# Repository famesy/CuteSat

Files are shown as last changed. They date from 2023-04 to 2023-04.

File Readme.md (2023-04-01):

# CubeSat PCB Design for Reliable Space Missions

CubeSat is an affordable and popular educational platform for deploying payloads into orbit. However, many university-level missions fail at a rate of around 50%. The primary reason for this is the difficulty of adapting an existing design, which results in poorly designed hardware for the harsh environment of space and a lack of failure handling software.

To address this problem, we have developed an expandable, low-cost printed circuit board (PCB) that can be stacked and includes the following components:

- Power supply unit
- Microcontroller
- Several sensors
- Watchdog
- Communication bus isolation
- External memory

We have used a component selection methodology that is based on existing research and adapted it to our design. We have also implemented a software Hamming error-correction code to protect the data.

Since our PCBs are modular, readers can design their own system using our design as a starting point. We offer failure handler software and hardware that can be easily integrated into their design. Our ultimate goal is to make space studies more accessible to everyone, increase the success rate, and allow people to focus on their missions rather than the hectic development.

Lastly, we intend to make our project open source so that it can continue to grow and improve over time. We hope that this project will develop into a community where people can discuss their designs and share their changes and knowledge for various missions.

Thank you for considering our CubeSat PCB design for your space mission needs.

## Project Components
This project includes two distinct folders: hardware and software.

### Hardware
The hardware folder contains four PCB designs that were used in our mission:

#### MCU (base PCB)

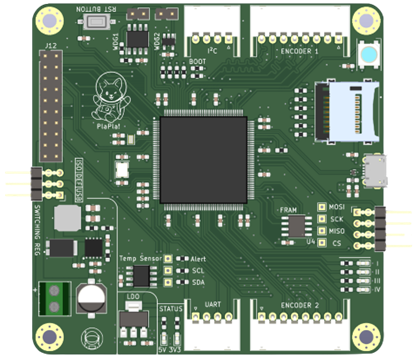
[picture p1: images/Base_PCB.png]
Base PCB


#### Motor driver (payload PCB)

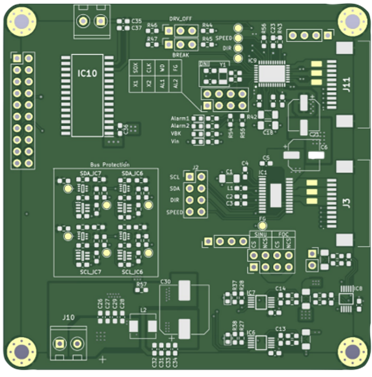
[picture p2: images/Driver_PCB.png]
Driver PCB


#### Encoder (payload PCB)

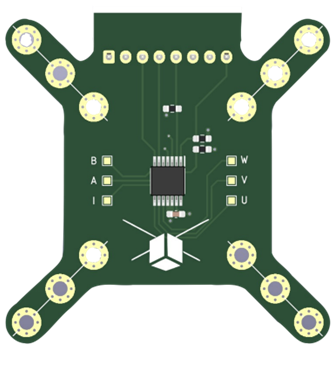
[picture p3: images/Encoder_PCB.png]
Encoder PCB


#### ST-Link adapter

### Software
The software folder contains STM32 projects that include libraries for interfacing with the sensors and implementing error detection and correction algorithms.

### How its look when assemble

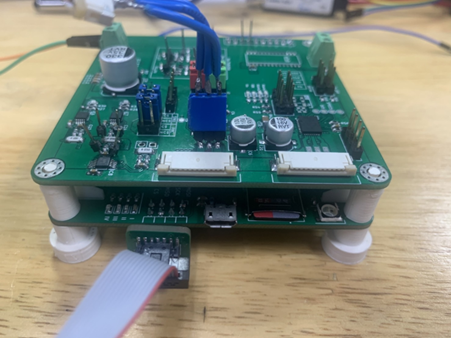
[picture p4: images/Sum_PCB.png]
SUM PCB


####Thank you for your interest in our project!

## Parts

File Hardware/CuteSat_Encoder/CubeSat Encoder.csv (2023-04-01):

Source: | C:\Users\fame\Documents\KiCad Projects\CubeSat Encoder\CubeSat Encoder.kicad_sch
Date: | 19/01/2022 13:51:59
Tool: | Eeschema (6.0.0)
Generator: | C:\Program Files\KiCad\6.0\bin\scripting\plugins/bom_csv_grouped_by_value.py
Component Count: | 16
Individual Components:
Item | Qty | Reference(s) | Value | LibPart | Footprint | Datasheet | Arrow Part Number | Arrow Price/Stock | Description | Height | Manufacturer_Name | Manufacturer_Part_Number | Mouser Part Number | Mouser Price/Stock
 |  | C1 | 0.1u | Device:C_Small | Capacitor_SMD:C_0603_1608Metric_Pad1.08x0.95mm_HandSolder | ~
 |  | H1 | MountingHole_Pad | Mechanical:MountingHole_Pad | MountingHole:MountingHole_2.2mm_M2_Pad_Via | ~
 |  | H2 | MountingHole_Pad | Mechanical:MountingHole_Pad | MountingHole:MountingHole_2.2mm_M2_Pad_Via | ~
 |  | H3 | MountingHole_Pad | Mechanical:MountingHole_Pad | MountingHole:MountingHole_2.2mm_M2_Pad_Via | ~
 |  | H4 | MountingHole_Pad | Mechanical:MountingHole_Pad | MountingHole:MountingHole_2.2mm_M2_Pad_Via | ~
 |  | IC1 | AS5047U-HTSM | AS5047U-HTSM:AS5047U-HTSM | AS5047U:SOP65P640X120-14N | https://datasheet.datasheetarchive.com/originals/distributors/Datasheets_SAMA/c3ef85baf5c65a55d97fe066bf0af3b0.pdf | AS5047U-HTSM | https://www.arrow.com/en/products/as5047u-htsm/ams-ag?region=nac | AMS AS5047U-HTSM TSSOP14 LF T&RDP | 1.2 | ams | AS5047U-HTSM | 985-AS5047U-HTSM | https://www.mouser.co.uk/ProductDetail/ams/AS5047U-HTSM?qs=byeeYqUIh0NGoikretscuw%3D%3D
 |  | J1 | Conn_02x06_Odd_Even | Connector_Generic:Conn_02x06_Odd_Even | Connector_JST:JST_PHD_B12B-PHDSS_2x06_P2.00mm_Vertical | ~
 |  | R1 | 10k | Device:R_Small | Resistor_SMD:R_0603_1608Metric_Pad0.98x0.95mm_HandSolder | ~
 |  | R2 | 10k | Device:R_Small | Resistor_SMD:R_0603_1608Metric_Pad0.98x0.95mm_HandSolder | ~
 |  | R3 | 10k | Device:R_Small | Resistor_SMD:R_0603_1608Metric_Pad0.98x0.95mm_HandSolder | ~
 |  | TP1 | TestPoint | Connector:TestPoint | TestPoint:TestPoint_Pad_1.0x1.0mm | ~
 |  | TP2 | TestPoint | Connector:TestPoint | TestPoint:TestPoint_Pad_1.0x1.0mm | ~
 |  | TP3 | TestPoint | Connector:TestPoint | TestPoint:TestPoint_Pad_1.0x1.0mm | ~
 |  | TP4 | TestPoint | Connector:TestPoint | TestPoint:TestPoint_Pad_1.0x1.0mm | ~
 |  | TP5 | TestPoint | Connector:TestPoint | TestPoint:TestPoint_Pad_1.0x1.0mm | ~
 |  | TP6 | TestPoint | Connector:TestPoint | TestPoint:TestPoint_Pad_1.0x1.0mm | ~
Collated Components:
Item | Qty | Reference(s) | Value | LibPart | Footprint | Datasheet | Arrow Part Number | Arrow Price/Stock | Description | Height | Manufacturer_Name | Manufacturer_Part_Number | Mouser Part Number | Mouser Price/Stock
1 | 1 | C1 | 0.1u | Device:C_Small | Capacitor_SMD:C_0603_1608Metric_Pad1.08x0.95mm_HandSolder | ~
2 | 4 | H1, H2, H3, H4 | MountingHole_Pad | Mechanical:MountingHole_Pad | MountingHole:MountingHole_2.2mm_M2_Pad_Via | ~
3 | 1 | IC1 | AS5047U-HTSM | AS5047U-HTSM:AS5047U-HTSM | AS5047U:SOP65P640X120-14N | https://datasheet.datasheetarchive.com/originals/distributors/Datasheets_SAMA/c3ef85baf5c65a55d97fe066bf0af3b0.pdf | AS5047U-HTSM | https://www.arrow.com/en/products/as5047u-htsm/ams-ag?region=nac | AMS AS5047U-HTSM TSSOP14 LF T&RDP | 1.2 | ams | AS5047U-HTSM | 985-AS5047U-HTSM | https://www.mouser.co.uk/ProductDetail/ams/AS5047U-HTSM?qs=byeeYqUIh0NGoikretscuw%3D%3D
4 | 1 | J1 | Conn_02x06_Odd_Even | Connector_Generic:Conn_02x06_Odd_Even | Connector_JST:JST_PHD_B12B-PHDSS_2x06_P2.00mm_Vertical | ~
5 | 3 | R1, R2, R3 | 10k | Device:R_Small | Resistor_SMD:R_0603_1608Metric_Pad0.98x0.95mm_HandSolder | ~
6 | 6 | TP1, TP2, TP3, TP4, TP5, TP6 | TestPoint | Connector:TestPoint | TestPoint:TestPoint_Pad_1.0x1.0mm | ~

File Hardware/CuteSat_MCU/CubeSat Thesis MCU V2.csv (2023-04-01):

Source: | C:\Users\fame\Documents\KiCad Projects\CubeSat Thesis MCU V2\CubeSat Thesis MCU V2.kicad_sch
Date: | 19/01/2022 19:44:47
Tool: | Eeschema (6.0.0)
Generator: | C:\Program Files\KiCad\6.0\bin\scripting\plugins/bom_csv_grouped_by_value.py
Component Count: | 101
Individual Components:
Item | Qty | Reference(s) | Value | LibPart | Footprint | Datasheet | Arrow Part Number | Arrow Price/Stock | Description | Height | MFR | Manufacturer_Name | Manufacturer_Part_Number | Mfr | Mouser Part Number | Mouser Price/Stock
 |  | C1 | 47u | Device:C_Polarized_Small | Capacitor_SMD:CP_Elec_6.3x5.4 | ~ |  |  |  |  |  |  |  | EEE1VA470WP
 |  | C2 | 4.7u | Device:C_Small | Capacitor_SMD:C_0805_2012Metric | ~
 |  | C3 | 4.7u | Device:C_Small | Capacitor_SMD:C_0805_2012Metric | ~
 |  | C4 | 0.1u | Device:C_Small | Capacitor_SMD:C_0603_1608Metric | ~
 |  | C5 | 0.1u | Device:C_Small | Capacitor_SMD:C_0603_1608Metric | ~
 |  | C6 | 10u | Device:C_Small | Capacitor_SMD:C_0603_1608Metric | ~
 |  | C7 | 4.7n | Device:C_Small | Capacitor_SMD:C_0603_1608Metric | ~
 |  | C8 | 47u | Device:C_Small | Capacitor_SMD:C_0805_2012Metric | ~
 |  | C9 | 47u | Device:C_Small | Capacitor_SMD:C_0805_2012Metric | ~
 |  | C10 | 10p | Device:C_Small | Capacitor_SMD:C_0603_1608Metric | ~
 |  | C11 | 10p | Device:C_Small | Capacitor_SMD:C_0603_1608Metric | ~
 |  | C12 | 4p | Device:C_Small | Capacitor_SMD:C_0603_1608Metric | ~
 |  | C13 | 4p | Device:C_Small | Capacitor_SMD:C_0603_1608Metric | ~
 |  | C14 | 2.2u | Device:C_Small | Capacitor_SMD:C_0603_1608Metric | ~
 |  | C15 | 2.2u | Device:C_Small | Capacitor_SMD:C_0603_1608Metric | ~
 |  | C16 | 4.7u | Device:C_Small | Capacitor_SMD:C_0603_1608Metric | ~
 |  | C17 | 0.1u | Device:C_Small | Capacitor_SMD:C_0603_1608Metric | ~
 |  | C18 | 0.1u | Device:C_Small | Capacitor_SMD:C_0603_1608Metric | ~
 |  | C19 | 0.1u | Device:C_Small | Capacitor_SMD:C_0603_1608Metric | ~
 |  | C20 | 0.1u | Device:C_Small | Capacitor_SMD:C_0603_1608Metric | ~
 |  | C21 | 0.1u | Device:C_Small | Capacitor_SMD:C_0603_1608Metric | ~
 |  | C22 | 0.1u | Device:C_Small | Capacitor_SMD:C_0603_1608Metric | ~
 |  | C23 | 0.1u | Device:C_Small | Capacitor_SMD:C_0603_1608Metric | ~
 |  | C24 | 0.1u | Device:C_Small | Capacitor_SMD:C_0603_1608Metric | ~
 |  | C25 | 0.1u | Device:C_Small | Capacitor_SMD:C_0603_1608Metric | ~
 |  | C26 | 0.1u | Device:C_Small | Capacitor_SMD:C_0603_1608Metric | ~
 |  | C27 | 0.1u | Device:C_Small | Capacitor_SMD:C_0603_1608Metric | ~
 |  | C28 | 0.1u | Device:C_Small | Capacitor_SMD:C_0603_1608Metric | ~
 |  | C29 | 0.1u | Device:C_Small | Capacitor_SMD:C_0603_1608Metric | ~
 |  | C30 | 0.1u | Device:C_Small | Capacitor_SMD:C_0603_1608Metric | ~
 |  | C31 | 0.1u | Device:C_Small | Capacitor_SMD:C_0603_1608Metric | ~
 |  | C32 | 0.1u | Device:C_Small | Capacitor_SMD:C_0603_1608Metric | ~
 |  | C33 | 0.1u | Device:C_Small | Capacitor_SMD:C_0603_1608Metric | ~
 |  | C34 | 1u | Device:C_Small | Capacitor_SMD:C_0603_1608Metric | ~
 |  | C35 | 0.1u | Device:C_Small | Capacitor_SMD:C_0603_1608Metric | ~
 |  | C36 | 0.1u | Device:C_Small | Capacitor_SMD:C_0603_1608Metric | ~
 |  | C37 | 0.1u | Device:C_Small | Capacitor_SMD:C_0603_1608Metric | ~
 |  | D1 | GREEN | Device:LED_Small | LED_SMD:LED_0603_1608Metric | ~
 |  | D2 | GREEN | Device:LED_Small | LED_SMD:LED_0603_1608Metric | ~
 |  | D3 | SDT5100LP5-13 | Device:D_Schottky_AAK | SDT5100LP5-13:SDT5100LP513 | ~
 |  | D4 | GREEN | Device:LED_Small | LED_SMD:LED_0603_1608Metric | ~
 |  | D5 | GREEN | Device:LED_Small | LED_SMD:LED_0603_1608Metric | ~
 |  | D6 | WS2812B | LED:WS2812B | LED_SMD:LED_WS2812B_PLCC4_5.0x5.0mm_P3.2mm | https://cdn-shop.adafruit.com/datasheets/WS2812B.pdf
 |  | H1 | M3 | Mechanical:MountingHole_Pad | MountingHole:MountingHole_3.2mm_M3_Pad_Via | ~
 |  | H2 | M3 | Mechanical:MountingHole_Pad | MountingHole:MountingHole_3.2mm_M3_Pad_Via | ~
 |  | H3 | M3 | Mechanical:MountingHole_Pad | MountingHole:MountingHole_3.2mm_M3_Pad_Via | ~
 |  | H4 | M3 | Mechanical:MountingHole_Pad | MountingHole:MountingHole_3.2mm_M3_Pad_Via | ~
 |  | IC1 | LMR14030QDPRRQ1 | LMR14030QDPRRQ1:LMR14030QDPRRQ1 | LMR14030QDPRRQ1:SON80P400X400X80-11N-D | http://www.ti.com/lit/gpn/lmr14030-q1 | LMR14030QDPRRQ1 | https://www.arrow.com/en/products/lmr14030qdprrq1/texas-instruments?region=nac | Automotive 40V, 3.5A SIMPLE SWITCHER&#174;, 2.2MHz Step-Down Regulator with 40uA IQ | 0.8 |  | Texas Instruments | LMR14030QDPRRQ1 |  | 595-LMR14030QDPRRQ1 | https://www.mouser.co.uk/ProductDetail/Texas-Instruments/LMR14030QDPRRQ1?qs=osPbIpHqQ9W8GWWKtDyJIw%3D%3D
 |  | IC2 | STM32H743ZIT6 | STM32H743ZIT6:STM32H743ZIT6 | STM32H743ZIT6:QFP50P2200X2200X160-144N | https://www.st.com/resource/en/datasheet/stm32h743zi.pdf | STM32H743ZIT6 | https://www.arrow.com/en/products/stm32h743zit6/stmicroelectronics?region=nac | ARM Microcontrollers - MCU High-performance and DSP with DP-FPU, ARM Cortex-M7 MCU with 2MBytes Flash, 1MB RAM, 400 MHz CPU, Art Accelerator, L1 cache, external memory interface, large set of peripherals | 1.6 |  | STMicroelectronics | STM32H743ZIT6 |  | 511-STM32H743ZIT6 | https://www.mouser.co.uk/ProductDetail/STMicroelectronics/STM32H743ZIT6?qs=FNcb6ahWXRyuf15GdgTu%252Bw%3D%3D
 |  | IC3 | MAX706RESA+T | MAX706RESA+T:MAX706RESA+T | MAX706RESA+T:SOIC127P600X175-8N | https://pdfserv.maximintegrated.com/en/ds/MAX706AP-MAX708T.pdf |  |  | MAXIM INTEGRATED PRODUCTS - MAX706RESA+T - MPU Supervisor, 1.2V-5.5V supply, Active-Low, Push-Pull reset, 200 ms delay/2.63V threshold, NSOIC-8 | 1.75 |  | Maxim Integrated | MAX706RESA+T |  | 700-MAX706RESAT | https://www.mouser.co.uk/ProductDetail/Maxim-Integrated/MAX706RESA%2bT?qs=ZlLWvsADX%2FmYLflDyxj85g%3D%3D
 |  | IC4 | TMP75CQDRQ1 | TMP75CQDRQ1:TMP75CQDRQ1 | TMP75CQDRQ1:SOIC127P600X175-8N | http://www.ti.com/lit/gpn/tmp75c-q1 | TMP75CQDRQ1 | https://www.arrow.com/en/products/tmp75cqdrq1/texas-instruments?region=nac | 1C Accuracy, Digital Temp Sensor w/ 2-Wire Interface & Alert | 1.75 |  | Texas Instruments | TMP75CQDRQ1 |  | 595-TMP75CQDRQ1 | https://www.mouser.co.uk/ProductDetail/Texas-Instruments/TMP75CQDRQ1?qs=0C8XhJW8e4rRSEgU5J%252BNEg%3D%3D
 |  | J1 | Conn_01x03 | Connector_Generic:Conn_01x03 | Connector_PinSocket_2.54mm:PinSocket_1x03_P2.54mm_Vertical | ~
 |  | J2 | Terminal Block 2mm 01x02 | Connector_Generic:Conn_01x02 | Screw:terminal_2p_3.81 | ~
 |  | J3 | USB_B_Micro | Connector:USB_B_Micro | Connector_USB:USB_Micro-B_Molex-105017-0001 | ~
 |  | J4 | WDT2_EN_JUMPER | Connector_Generic:Conn_01x02 | Connector_PinHeader_2.54mm:PinHeader_1x02_P2.54mm_Vertical | ~
 |  | J5 | UART_Conn | Connector_Generic:Conn_01x04 | Connector_JST:JST_XH_S4B-XH-A-1_1x04_P2.50mm_Horizontal | ~
 |  | J6 | I2C_Conn_1 | Connector_Generic:Conn_01x04 | Connector_JST:JST_XH_S4B-XH-A-1_1x04_P2.50mm_Horizontal | ~
 |  | J7 | WDT1_EN_JUMPER | Connector_Generic:Conn_01x02 | Connector_PinHeader_2.54mm:PinHeader_1x02_P2.54mm_Vertical | ~
 |  | J8 | Encoder_Conn_1 | Connector_Generic:Conn_01x08 | Connector_JST:JST_XH_S8B-XH-A-1_1x08_P2.50mm_Horizontal | ~
 |  | J9 | Encoder_Conn_1 | Connector_Generic:Conn_01x08 | Connector_JST:JST_XH_S8B-XH-A-1_1x08_P2.50mm_Horizontal | ~
 |  | J10 | Conn_02x04_Odd_Even | Connector_Generic:Conn_02x04_Odd_Even | Connector_PinHeader_2.54mm:PinHeader_2x04_P2.54mm_Vertical | ~
 |  | J11 | 0472192001 | 0472192001:0472192001 | 0472192001:0472192001 | https://www.molex.com/pdm_docs/sd/472192001_sd.pdf | 0472192001 | https://www.arrow.com/en/products/0472192001/molex | Memory Card Connectors 1.10MM MICRO SD 08P HINGE TYPE | 1.9 |  | Molex | 0472192001 |  | N/A | https://www.mouser.com/Search/Refine.aspx?Keyword=N%2FA
 |  | J12 | Conn_02x10_Odd_Even | Connector_Generic:Conn_02x10_Odd_Even | Connector_PinHeader_2.54mm:PinHeader_2x10_P2.54mm_Vertical | ~
 |  | L1 | 6.8u | Device:L_Small | VLS6045EX-6R8M:VLS6045 | ~ |  |  |  |  | FXL0420-6R8-M
 |  | L2 | 47n | Device:L_Small | Inductor_SMD:L_0603_1608Metric | ~
 |  | R1 | 470 | Device:R_Small | Resistor_SMD:R_0603_1608Metric | ~
 |  | R2 | 470 | Device:R_Small | Resistor_SMD:R_0603_1608Metric | ~
 |  | R3 | 0 | Device:R_Small | Resistor_SMD:R_0603_1608Metric | ~
 |  | R4 | 23.4k | Device:R_Small | Resistor_SMD:R_0603_1608Metric | ~
 |  | R5 | 100k | Device:R_Small | Resistor_SMD:R_0603_1608Metric | ~
 |  | R6 | 17.8k | Device:R_Small | Resistor_SMD:R_0603_1608Metric | ~
 |  | R7 | 470 | Device:R_Small | Resistor_SMD:R_0603_1608Metric | ~
 |  | R8 | 3.3k | Device:R_Small | Resistor_SMD:R_0603_1608Metric | ~
 |  | R9 | 3.3k | Device:R_Small | Resistor_SMD:R_0603_1608Metric | ~
 |  | R10 | 0 | Device:R_Small | Resistor_SMD:R_0603_1608Metric_Pad0.98x0.95mm_HandSolder | ~
 |  | R11 | 10k | Device:R_Small | Resistor_SMD:R_0603_1608Metric_Pad0.98x0.95mm_HandSolder | ~
 |  | R12 | 470 | Device:R_Small | Resistor_SMD:R_0603_1608Metric | ~
 |  | R13 | 3.3k | Device:R_Small | Resistor_SMD:R_0603_1608Metric | ~
 |  | R14 | 3.3k | Device:R_Small | Resistor_SMD:R_0603_1608Metric | ~
 |  | R15 | 3.3k | Device:R_Small | Resistor_SMD:R_0603_1608Metric | ~
 |  | R16 | 3.3k | Device:R_Small | Resistor_SMD:R_0603_1608Metric | ~
 |  | R17 | 0 | Device:R_Small | Resistor_SMD:R_0603_1608Metric_Pad0.98x0.95mm_HandSolder | ~
 |  | R18 | 0 | Device:R_Small | Resistor_SMD:R_0603_1608Metric_Pad0.98x0.95mm_HandSolder | ~
 |  | R19 | 10k | Device:R_Small | Resistor_SMD:R_0603_1608Metric | ~
 |  | R20 | 10k | Device:R_Small | Resistor_SMD:R_0603_1608Metric | ~
 |  | R21 | 10k | Device:R_Small | Resistor_SMD:R_0603_1608Metric | ~
 |  | R22 | 22 | Device:R_Small | Resistor_SMD:R_0603_1608Metric | ~
 |  | R23 | 10k | Device:R_Small | Resistor_SMD:R_0603_1608Metric | ~
 |  | R24 | 10k | Device:R_Small | Resistor_SMD:R_0603_1608Metric | ~
 |  | R25 | 10k | Device:R_Small | Resistor_SMD:R_0603_1608Metric | ~
 |  | S1 | TS-1101-C-W | TS-1101-C-W:TS-1101-C-W | TS-1101-C-W:TS1101CW | http://www.helloxkb.com/public/images/pdf/TS-1101-C-W-.pdf |  |  | Tactile Switches SPST 6.00mm x 3.60mm 0.60mm 50mA @ 12VDC SMD RoHS | 2.6 |  | XKB Connectivity | TS-1101-C-W
 |  | TP1 | TestPoint | Connector:TestPoint | TestPoint:TestPoint_THTPad_1.0x1.0mm_Drill0.5mm | ~
 |  | TP2 | TestPoint | Connector:TestPoint | TestPoint:TestPoint_THTPad_1.0x1.0mm_Drill0.5mm | ~
 |  | TP3 | TestPoint | Connector:TestPoint | TestPoint:TestPoint_THTPad_1.0x1.0mm_Drill0.5mm | ~
 |  | TP4 | TestPoint | Connector:TestPoint | TestPoint:TestPoint_THTPad_1.0x1.0mm_Drill0.5mm | ~
 |  | U1 | LD1117S33TR_SOT223 | Regulator_Linear:LD1117S33TR_SOT223 | Package_TO_SOT_SMD:SOT-223-3_TabPin2 | http://www.st.com/st-web-ui/static/active/en/resource/technical/document/datasheet/CD00000544.pdf
 |  | U2 | TPD2EUSB30 | Power_Protection:TPD2EUSB30 | Package_TO_SOT_SMD:Texas_DRT-3 | http://www.ti.com/lit/ds/symlink/tpd2eusb30a.pdf
 |  | U3 | TPS3828-33DBVR | TPS3828-33DBVR:TPS3828-33DBVR | TPS3828-33DBVR:SOT95P280X145-5N | http://www.ti.com/lit/gpn/tps3828 | TPS3828-33DBVR | https://www.arrow.com/en/products/tps3828-33dbvr/texas-instruments | Texas Instruments TPS3828-33DBVR, Processor Supervisor 0 5.8 V, WDT, Reset Input, 5-Pin SOT-23 | 1.45 |  | Texas Instruments | TPS3828-33DBVR |  | 595-TPS3828-33DBVR | https://www.mouser.co.uk/ProductDetail/Texas-Instruments/TPS3828-33DBVR?qs=zwk82MlA57bHNcMUTEMxAg%3D%3D
 |  | U4 | MB85RS64 | Memory_NVRAM:MB85RS64 | Package_SO:SSOP-8_3.9x5.05mm_P1.27mm | http://www.fujitsu.com/downloads/MICRO/fme/fram/datasheet-MB85RS64.pdf
 |  | Y1 | 16 MHz | Device:Crystal_GND24_Small | Crystal:Crystal_SMD_3225-4Pin_3.2x2.5mm | ~
 |  | Y2 | 32.768 kHz | Device:Crystal_Small | Crystal:Crystal_SMD_2012-2Pin_2.0x1.2mm | ~
Collated Components:
Item | Qty | Reference(s) | Value | LibPart | Footprint | Datasheet | Arrow Part Number | Arrow Price/Stock | Description | Height | MFR | Manufacturer_Name | Manufacturer_Part_Number | Mfr | Mouser Part Number | Mouser Price/Stock
1 | 1 | C1 | 47u | Device:C_Polarized_Small | Capacitor_SMD:CP_Elec_6.3x5.4 | ~ |  |  |  |  |  |  |  | EEE1VA470WP
2 | 2 | C2, C3 | 4.7u | Device:C_Small | Capacitor_SMD:C_0805_2012Metric | ~
3 | 22 | C4, C5, C17, C18, C19, C20, C21, C22, C23, C24, C25, C26, C27, C28, C29, C30, C31, C32, C33, C35, C36, C37 | 0.1u | Device:C_Small | Capacitor_SMD:C_0603_1608Metric | ~
4 | 1 | C6 | 10u | Device:C_Small | Capacitor_SMD:C_0603_1608Metric | ~
5 | 1 | C7 | 4.7n | Device:C_Small | Capacitor_SMD:C_0603_1608Metric | ~
6 | 2 | C8, C9 | 47u | Device:C_Small | Capacitor_SMD:C_0805_2012Metric | ~
7 | 2 | C10, C11 | 10p | Device:C_Small | Capacitor_SMD:C_0603_1608Metric | ~
8 | 2 | C12, C13 | 4p | Device:C_Small | Capacitor_SMD:C_0603_1608Metric | ~
9 | 2 | C14, C15 | 2.2u | Device:C_Small | Capacitor_SMD:C_0603_1608Metric | ~
10 | 1 | C16 | 4.7u | Device:C_Small | Capacitor_SMD:C_0603_1608Metric | ~
11 | 1 | C34 | 1u | Device:C_Small | Capacitor_SMD:C_0603_1608Metric | ~
12 | 4 | D1, D2, D4, D5 | GREEN | Device:LED_Small | LED_SMD:LED_0603_1608Metric | ~
13 | 1 | D3 | SDT5100LP5-13 | Device:D_Schottky_AAK | SDT5100LP5-13:SDT5100LP513 | ~
14 | 1 | D6 | WS2812B | LED:WS2812B | LED_SMD:LED_WS2812B_PLCC4_5.0x5.0mm_P3.2mm | https://cdn-shop.adafruit.com/datasheets/WS2812B.pdf
15 | 4 | H1, H2, H3, H4 | M3 | Mechanical:MountingHole_Pad | MountingHole:MountingHole_3.2mm_M3_Pad_Via | ~
16 | 1 | IC1 | LMR14030QDPRRQ1 | LMR14030QDPRRQ1:LMR14030QDPRRQ1 | LMR14030QDPRRQ1:SON80P400X400X80-11N-D | http://www.ti.com/lit/gpn/lmr14030-q1 | LMR14030QDPRRQ1 | https://www.arrow.com/en/products/lmr14030qdprrq1/texas-instruments?region=nac | Automotive 40V, 3.5A SIMPLE SWITCHER&#174;, 2.2MHz Step-Down Regulator with 40uA IQ | 0.8 |  | Texas Instruments | LMR14030QDPRRQ1 |  | 595-LMR14030QDPRRQ1 | https://www.mouser.co.uk/ProductDetail/Texas-Instruments/LMR14030QDPRRQ1?qs=osPbIpHqQ9W8GWWKtDyJIw%3D%3D
17 | 1 | IC2 | STM32H743ZIT6 | STM32H743ZIT6:STM32H743ZIT6 | STM32H743ZIT6:QFP50P2200X2200X160-144N | https://www.st.com/resource/en/datasheet/stm32h743zi.pdf | STM32H743ZIT6 | https://www.arrow.com/en/products/stm32h743zit6/stmicroelectronics?region=nac | ARM Microcontrollers - MCU High-performance and DSP with DP-FPU, ARM Cortex-M7 MCU with 2MBytes Flash, 1MB RAM, 400 MHz CPU, Art Accelerator, L1 cache, external memory interface, large set of peripherals | 1.6 |  | STMicroelectronics | STM32H743ZIT6 |  | 511-STM32H743ZIT6 | https://www.mouser.co.uk/ProductDetail/STMicroelectronics/STM32H743ZIT6?qs=FNcb6ahWXRyuf15GdgTu%252Bw%3D%3D
18 | 1 | IC3 | MAX706RESA+T | MAX706RESA+T:MAX706RESA+T | MAX706RESA+T:SOIC127P600X175-8N | https://pdfserv.maximintegrated.com/en/ds/MAX706AP-MAX708T.pdf |  |  | MAXIM INTEGRATED PRODUCTS - MAX706RESA+T - MPU Supervisor, 1.2V-5.5V supply, Active-Low, Push-Pull reset, 200 ms delay/2.63V threshold, NSOIC-8 | 1.75 |  | Maxim Integrated | MAX706RESA+T |  | 700-MAX706RESAT | https://www.mouser.co.uk/ProductDetail/Maxim-Integrated/MAX706RESA%2bT?qs=ZlLWvsADX%2FmYLflDyxj85g%3D%3D
19 | 1 | IC4 | TMP75CQDRQ1 | TMP75CQDRQ1:TMP75CQDRQ1 | TMP75CQDRQ1:SOIC127P600X175-8N | http://www.ti.com/lit/gpn/tmp75c-q1 | TMP75CQDRQ1 | https://www.arrow.com/en/products/tmp75cqdrq1/texas-instruments?region=nac | 1C Accuracy, Digital Temp Sensor w/ 2-Wire Interface & Alert | 1.75 |  | Texas Instruments | TMP75CQDRQ1 |  | 595-TMP75CQDRQ1 | https://www.mouser.co.uk/ProductDetail/Texas-Instruments/TMP75CQDRQ1?qs=0C8XhJW8e4rRSEgU5J%252BNEg%3D%3D
20 | 1 | J1 | Conn_01x03 | Connector_Generic:Conn_01x03 | Connector_PinSocket_2.54mm:PinSocket_1x03_P2.54mm_Vertical | ~
21 | 1 | J2 | Terminal Block 2mm 01x02 | Connector_Generic:Conn_01x02 | Screw:terminal_2p_3.81 | ~
22 | 1 | J3 | USB_B_Micro | Connector:USB_B_Micro | Connector_USB:USB_Micro-B_Molex-105017-0001 | ~
23 | 1 | J4 | WDT2_EN_JUMPER | Connector_Generic:Conn_01x02 | Connector_PinHeader_2.54mm:PinHeader_1x02_P2.54mm_Vertical | ~
24 | 1 | J5 | UART_Conn | Connector_Generic:Conn_01x04 | Connector_JST:JST_XH_S4B-XH-A-1_1x04_P2.50mm_Horizontal | ~
25 | 1 | J6 | I2C_Conn_1 | Connector_Generic:Conn_01x04 | Connector_JST:JST_XH_S4B-XH-A-1_1x04_P2.50mm_Horizontal | ~
26 | 1 | J7 | WDT1_EN_JUMPER | Connector_Generic:Conn_01x02 | Connector_PinHeader_2.54mm:PinHeader_1x02_P2.54mm_Vertical | ~
27 | 2 | J8, J9 | Encoder_Conn_1 | Connector_Generic:Conn_01x08 | Connector_JST:JST_XH_S8B-XH-A-1_1x08_P2.50mm_Horizontal | ~
28 | 1 | J10 | Conn_02x04_Odd_Even | Connector_Generic:Conn_02x04_Odd_Even | Connector_PinHeader_2.54mm:PinHeader_2x04_P2.54mm_Vertical | ~
29 | 1 | J11 | 0472192001 | 0472192001:0472192001 | 0472192001:0472192001 | https://www.molex.com/pdm_docs/sd/472192001_sd.pdf | 0472192001 | https://www.arrow.com/en/products/0472192001/molex | Memory Card Connectors 1.10MM MICRO SD 08P HINGE TYPE | 1.9 |  | Molex | 0472192001 |  | N/A | https://www.mouser.com/Search/Refine.aspx?Keyword=N%2FA
30 | 1 | J12 | Conn_02x10_Odd_Even | Connector_Generic:Conn_02x10_Odd_Even | Connector_PinHeader_2.54mm:PinHeader_2x10_P2.54mm_Vertical | ~
31 | 1 | L1 | 6.8u | Device:L_Small | VLS6045EX-6R8M:VLS6045 | ~ |  |  |  |  | FXL0420-6R8-M
32 | 1 | L2 | 47n | Device:L_Small | Inductor_SMD:L_0603_1608Metric | ~
33 | 4 | R1, R2, R7, R12 | 470 | Device:R_Small | Resistor_SMD:R_0603_1608Metric | ~
34 | 1 | R3 | 0 | Device:R_Small | Resistor_SMD:R_0603_1608Metric | ~
35 | 1 | R4 | 23.4k | Device:R_Small | Resistor_SMD:R_0603_1608Metric | ~
36 | 1 | R5 | 100k | Device:R_Small | Resistor_SMD:R_0603_1608Metric | ~
37 | 1 | R6 | 17.8k | Device:R_Small | Resistor_SMD:R_0603_1608Metric | ~
38 | 6 | R8, R9, R13, R14, R15, R16 | 3.3k | Device:R_Small | Resistor_SMD:R_0603_1608Metric | ~
39 | 3 | R10, R17, R18 | 0 | Device:R_Small | Resistor_SMD:R_0603_1608Metric_Pad0.98x0.95mm_HandSolder | ~
40 | 1 | R11 | 10k | Device:R_Small | Resistor_SMD:R_0603_1608Metric_Pad0.98x0.95mm_HandSolder | ~
41 | 6 | R19, R20, R21, R23, R24, R25 | 10k | Device:R_Small | Resistor_SMD:R_0603_1608Metric | ~
42 | 1 | R22 | 22 | Device:R_Small | Resistor_SMD:R_0603_1608Metric | ~
43 | 1 | S1 | TS-1101-C-W | TS-1101-C-W:TS-1101-C-W | TS-1101-C-W:TS1101CW | http://www.helloxkb.com/public/images/pdf/TS-1101-C-W-.pdf |  |  | Tactile Switches SPST 6.00mm x 3.60mm 0.60mm 50mA @ 12VDC SMD RoHS | 2.6 |  | XKB Connectivity | TS-1101-C-W
44 | 4 | TP1, TP2, TP3, TP4 | TestPoint | Connector:TestPoint | TestPoint:TestPoint_THTPad_1.0x1.0mm_Drill0.5mm | ~
45 | 1 | U1 | LD1117S33TR_SOT223 | Regulator_Linear:LD1117S33TR_SOT223 | Package_TO_SOT_SMD:SOT-223-3_TabPin2 | http://www.st.com/st-web-ui/static/active/en/resource/technical/document/datasheet/CD00000544.pdf
46 | 1 | U2 | TPD2EUSB30 | Power_Protection:TPD2EUSB30 | Package_TO_SOT_SMD:Texas_DRT-3 | http://www.ti.com/lit/ds/symlink/tpd2eusb30a.pdf
47 | 1 | U3 | TPS3828-33DBVR | TPS3828-33DBVR:TPS3828-33DBVR | TPS3828-33DBVR:SOT95P280X145-5N | http://www.ti.com/lit/gpn/tps3828 | TPS3828-33DBVR | https://www.arrow.com/en/products/tps3828-33dbvr/texas-instruments | Texas Instruments TPS3828-33DBVR, Processor Supervisor 0 5.8 V, WDT, Reset Input, 5-Pin SOT-23 | 1.45 |  | Texas Instruments | TPS3828-33DBVR |  | 595-TPS3828-33DBVR | https://www.mouser.co.uk/ProductDetail/Texas-Instruments/TPS3828-33DBVR?qs=zwk82MlA57bHNcMUTEMxAg%3D%3D
48 | 1 | U4 | MB85RS64 | Memory_NVRAM:MB85RS64 | Package_SO:SSOP-8_3.9x5.05mm_P1.27mm | http://www.fujitsu.com/downloads/MICRO/fme/fram/datasheet-MB85RS64.pdf
49 | 1 | Y1 | 16 MHz | Device:Crystal_GND24_Small | Crystal:Crystal_SMD_3225-4Pin_3.2x2.5mm | ~
50 | 1 | Y2 | 32.768 kHz | Device:Crystal_Small | Crystal:Crystal_SMD_2012-2Pin_2.0x1.2mm | ~

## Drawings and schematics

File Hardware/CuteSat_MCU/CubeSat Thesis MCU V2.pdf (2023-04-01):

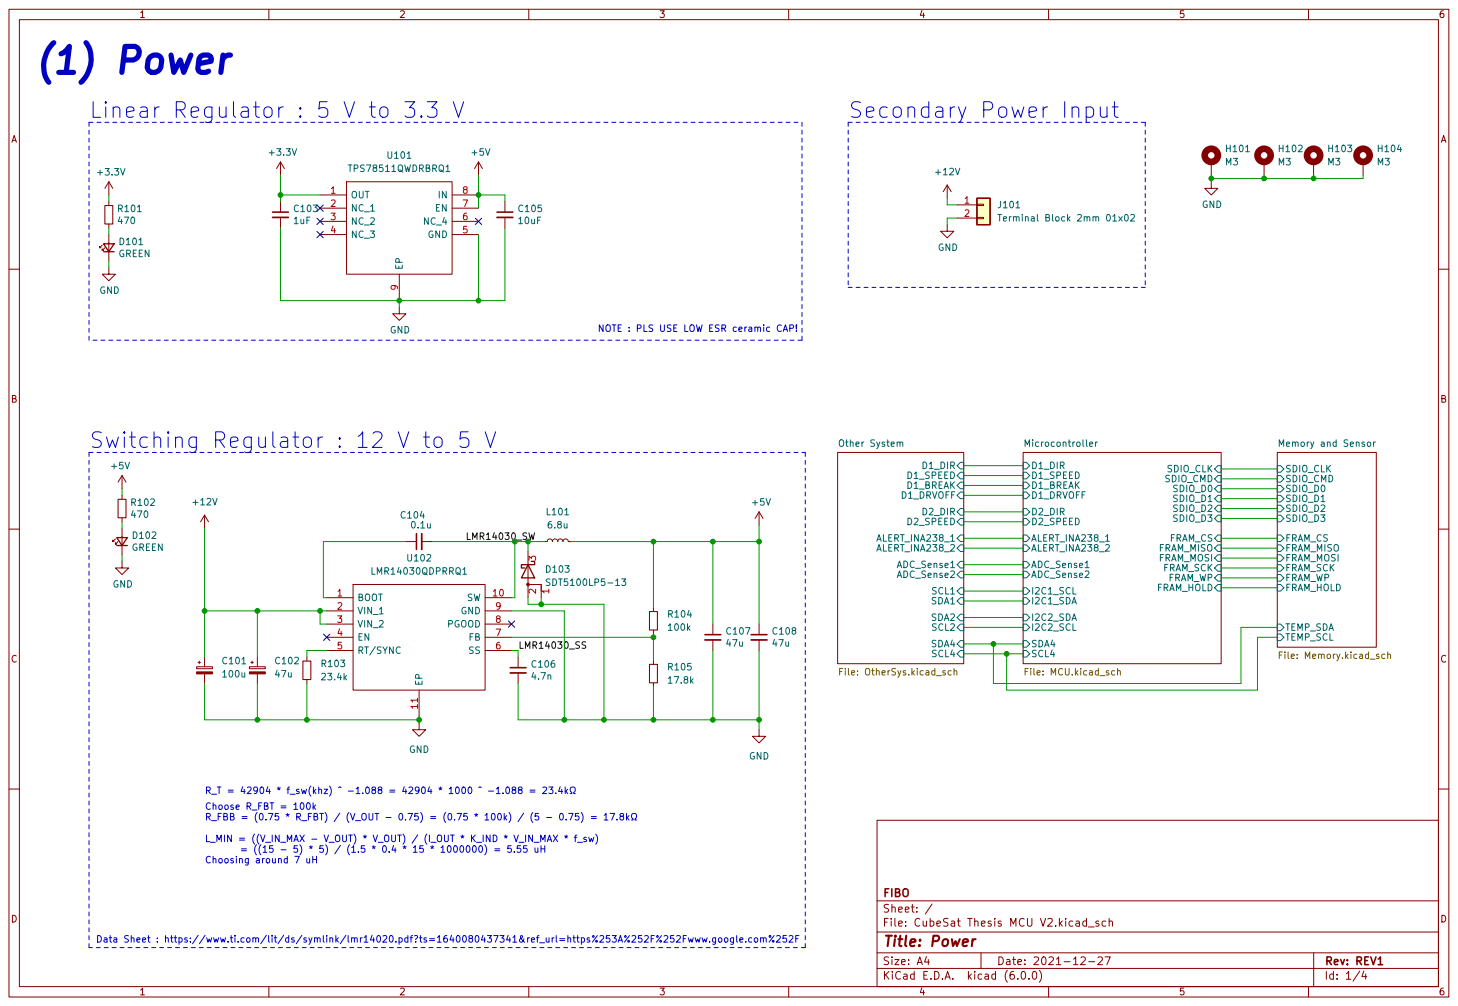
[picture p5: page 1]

NOTE : PLS USE LOW ESR ceramic CAP! þÿR_T = 42904 * f_sw(khz) ^ -1.088 = 42904 * 1000 ^ -1.088 = 23.4k©

File: CubeSat Thesis MCU V2.kicad_sch Sheet: / FIBO

Data Sheet : https://www.ti.com/lit/ds/symlink/lmr14020.pdf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

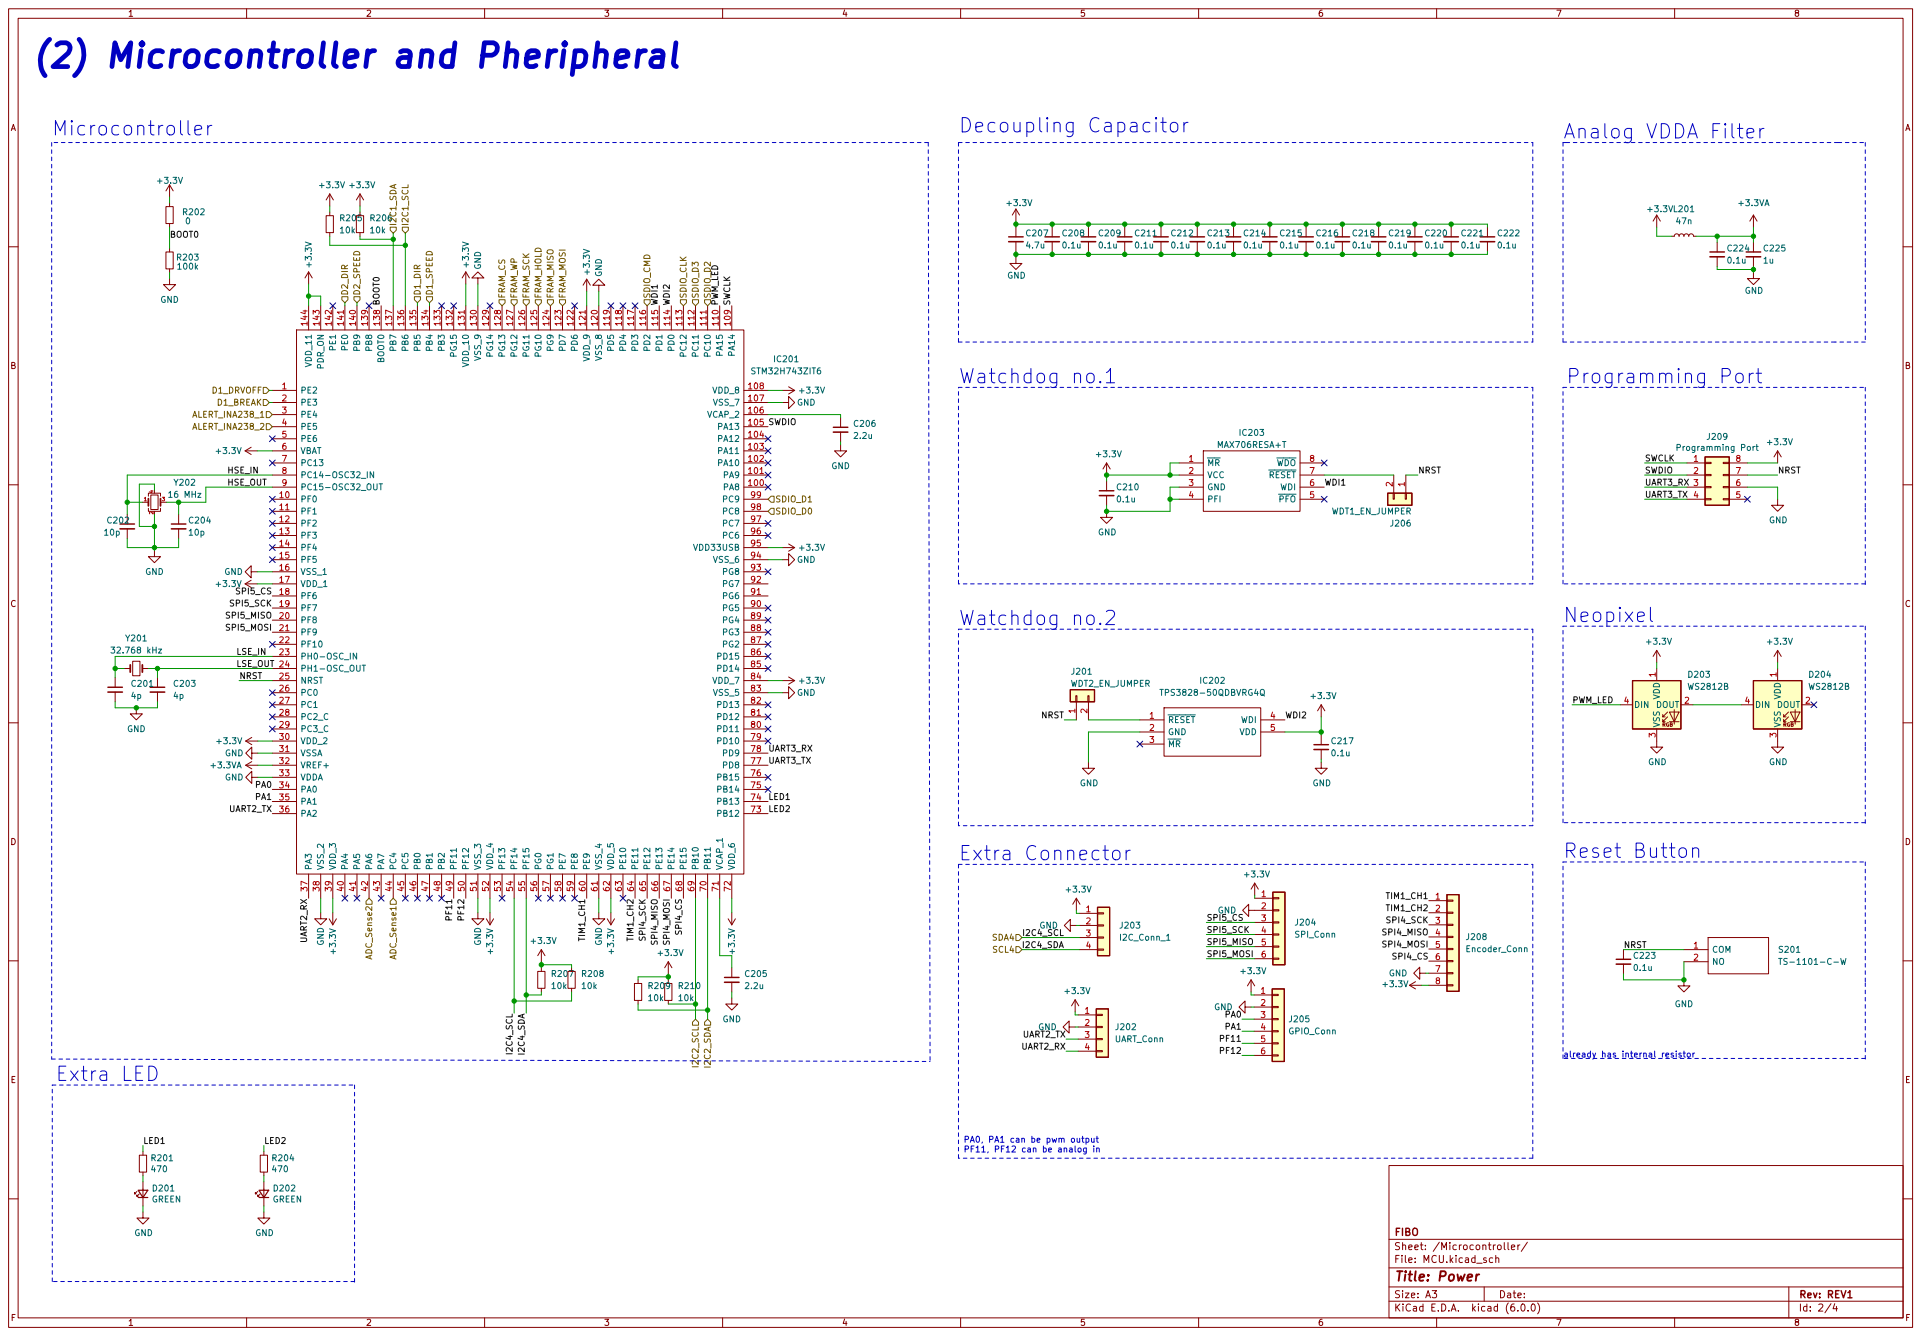
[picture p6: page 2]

already has internal resistor

PA0, PA1 can be pwm output
PF11, PF12 can be analog in

File: MCU.kicad_sch Sheet: /Microcontroller/ FIBO

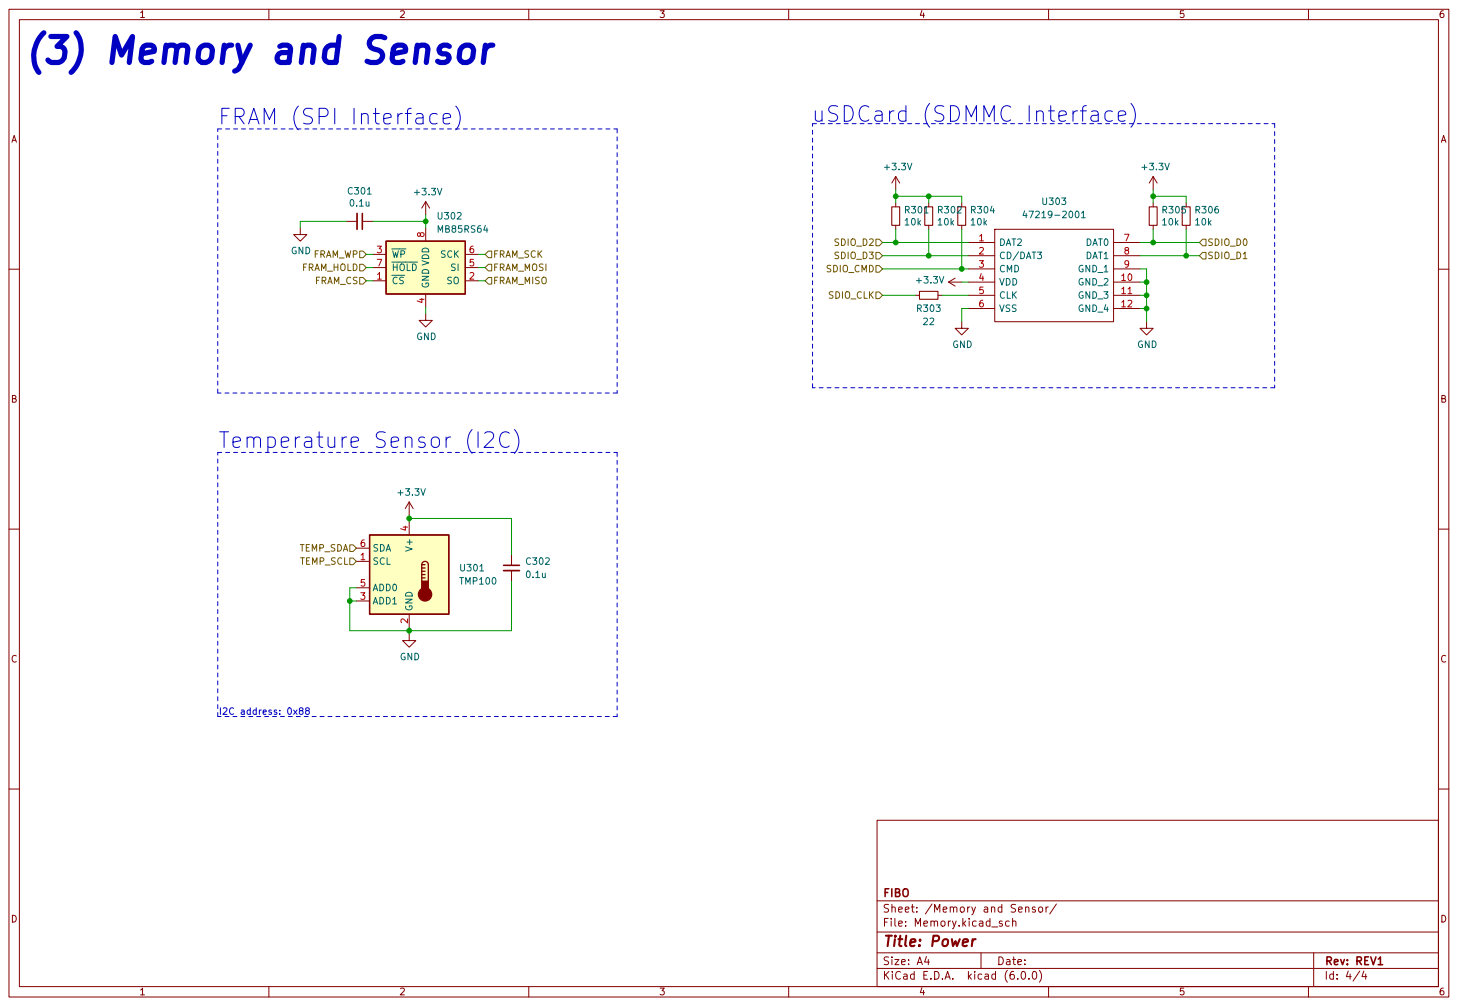
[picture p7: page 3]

4 SI 5 SCK 6 ~{HOLD} 7 VDD

GND

Sheet: /Memory and Sensor/ FIBO

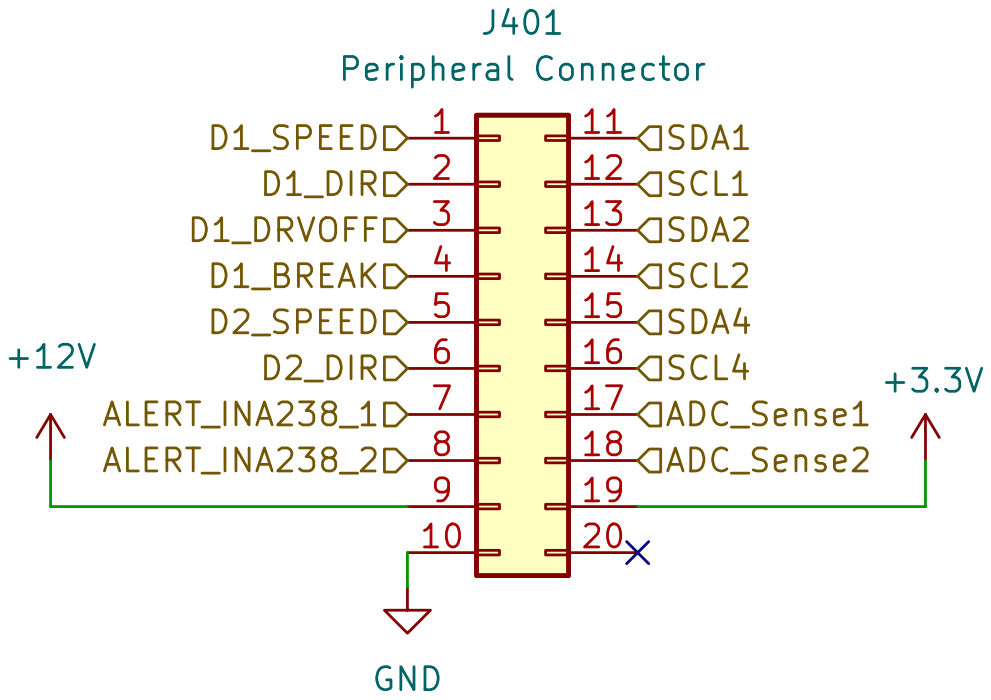
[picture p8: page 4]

Sheet: /Other System/ FIBO

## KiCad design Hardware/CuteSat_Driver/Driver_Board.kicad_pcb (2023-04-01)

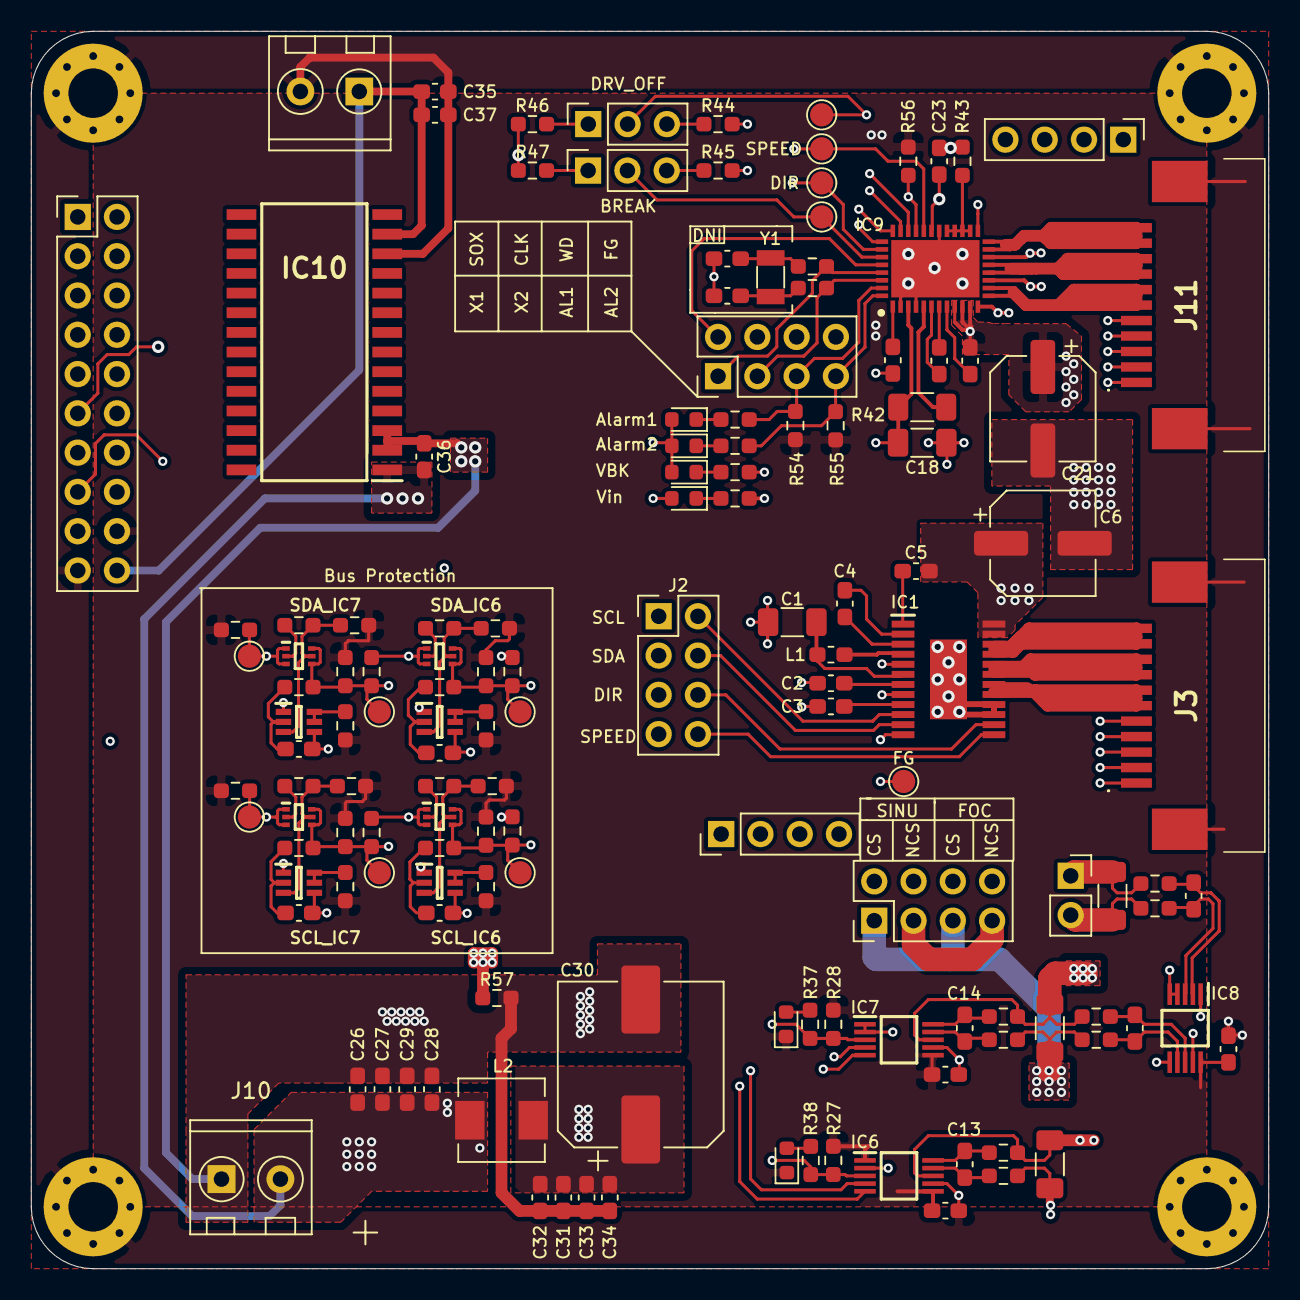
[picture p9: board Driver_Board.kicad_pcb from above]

Board: 4 copper layers, 80.0 x 80.0 mm, 145 parts (0 on the bottom side), 109 nets.

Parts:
C1, C18: 22uF; C_1206_3216Metric_Pad1.33x1.80mm_HandSolder
C2, C3, C4, C5, C11, C12, C17, C27, C32, C35: 0.1uF; C_0603_1608Metric_Pad1.08x0.95mm_HandSolder
C6, C21: 100uF; CP_Elec_6.3x5.4_Nichicon
C7, C8, C9, C10: 10nF; C_0603_1608Metric_Pad1.08x0.95mm_HandSolder
C13, C14, C15, C16, C19, C20, C23, C26, C31, C37: 1uF; C_0603_1608Metric_Pad1.08x0.95mm_HandSolder
C22: 47nF; C_0603_1608Metric_Pad1.08x0.95mm_HandSolder
C24, C25: ??nF; C_0603_1608Metric_Pad1.08x0.95mm_HandSolder
C28, C33: 0.01uF; C_0603_1608Metric_Pad1.08x0.95mm_HandSolder
C29, C34: 1nF; C_0603_1608Metric_Pad1.08x0.95mm_HandSolder
C30: 330uF; CP_Elec_10x10.5
C36: 2.2uF; C_0603_1608Metric_Pad1.08x0.95mm_HandSolder
D1, D2, D3, D4, D5, D6: LED; LED_0603_1608Metric
H1, H2, H3, H4: MountingHole_Pad; MountingHole_3.2mm_M3_Pad_Via
IC1: DRV10975ZPWPR; SOP65P640X120-25N
IC2, IC3, IC4, IC5: MMDT2222V-7; SOTFL50P162X60-6N
IC6, IC7: INA238AIDGST; SOP50P490X110-10N
IC8: INA2181A2QDGSRQ1; SOP50P490X110-10N
IC9: MCF8316A; QFN50P500X700X100-41N-D
IC10: DCP021205U; SOIC127P1033X265-28N
J1: Pin header 2*10p; PinHeader_2x10_P2.54mm_Vertical
J2, J4, J9: Pin Header 2*4; PinHeader_2x04_P2.54mm_Vertical
J3, J11: 1-84953-1; 1849531
J5: Pin header 2p; PinSocket_1x02_P2.54mm_Vertical
J6, J7: Pin Header 3p; PinSocket_1x03_P2.54mm_Vertical
J8, J12: Pin Header 4p; PinHeader_1x04_P2.54mm_Vertical
J10: Screw Terminal 2p; terminal_2p_3.81
J13: Screw_Terminal_2p; terminal_2p_3.81
L1: 47uF; L_0603_1608Metric_Pad1.05x0.95mm_HandSolder
L2: 1nH; L_Sunlord_MWSA0518_5.4x5.2mm
Q1, Q2, Q3, Q4: BSS138DWQ-7; SOT65P210X110-6N
R1, R2, R7, R8, R9, R11, R13, R14, R19, R20, R21, R23, R25, R26, R27, R28, R44, R45, R46, R47, R54, R55, R56: 10k; R_0603_1608Metric_Pad0.98x0.95mm_HandSolder
R3, R4, R15, R16: 680; R_0603_1608Metric_Pad0.98x0.95mm_HandSolder
R5, R6, R17, R18: 0r; R_0603_1608Metric_Pad0.98x0.95mm_HandSolder
R10, R12, R22, R24: 200k; R_0603_1608Metric_Pad0.98x0.95mm_HandSolder
R29, R30, R32, R33, R35, R36, R39, R40: 10r; R_0603_1608Metric_Pad0.98x0.95mm_HandSolder
R31, R34, R41: 0.1r; R_1206_3216Metric_Pad1.30x1.75mm_HandSolder
R37, R38: 4,7k; R_0603_1608Metric_Pad0.98x0.95mm_HandSolder
R42: 22r; R_1206_3216Metric_Pad1.30x1.75mm_HandSolder
R43, R48, R49, R57: 0R; R_0603_1608Metric_Pad0.98x0.95mm_HandSolder
R50, R51, R52, R53: 1k; R_0603_1608Metric_Pad0.98x0.95mm_HandSolder
TP1, TP2, TP3, TP4, TP5, TP6, TP7, TP8, TP9, TP10, TP11: TestPoint; TestPoint_Pad_D1.5mm
Y1: Crystal; Crystal_SMD_3215-2Pin_3.2x1.5mm

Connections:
+3V3: C11.1, C12.1, C17.1, D1.1, D2.1, IC6.1, IC6.6, IC7.6, IC8.10, J1.18, R1.1, R2.1, R7.1, R8.1, R9.1, R11.1, R13.1, R14.1, R19.1, R20.1, R21.1, R23.1, R25.1, R26.1, R27.2, R28.2, R54.1, R55.1, R56.1
+5VA: C35.2, C37.2, IC10.13, J1.20, J13.1
+12P: C30.1, C31.1, C32.1, C33.1, C34.1, IC6.8, IC7.8, J4.3, J4.7, J5.2, L2.2, R29.1, R31.1, R32.1, R34.1, R35.2, R39.1, R41.1
/12V: J1.17, R30.1, R31.2
/12V_D1: C20.2, C21.1, D6.2, IC9.9, IC9.10, IC9.11, J4.6, J4.8
/12V_D2: C5.1, C6.1, IC1.23, IC1.24, J4.2, J4.4
/AL_INA238_1: IC7.3, J1.13, R28.1, R37.1
/AL_INA238_2: IC6.3, J1.15, R27.1, R38.1
/D1_BREAK: IC9.35, J1.5, J7.2, TP10.1
/D1_DIR: IC9.34, J1.3, TP9.1
/D1_DRVOFF: IC9.21, J1.7, J6.2, TP11.1
/D1_SPEED: IC9.28, J1.1, TP8.1
/D2_DIR: J1.11, J2.5
/D2_SPEED: J1.9, J2.7
/Driver_DRV10975/D2_DIR_I: IC1.14, J2.6
/Driver_DRV10975/D2_FG: IC1.12, TP1.1
/Driver_DRV10975/D2_SCL_I: IC1.10, J2.2
/Driver_DRV10975/D2_SDA_I: IC1.11, J2.4
/Driver_DRV10975/D2_SPEED_I: IC1.13, J2.8
/Driver_DRV10975/U: IC1.17, IC1.18, J3.6, J3.7
/Driver_DRV10975/V: IC1.19, IC1.20, J3.8, J3.9
/Driver_DRV10975/W: IC1.21, IC1.22, J3.10, J3.11
/Driver_MCF8316A/AVDD: C23.1, IC9.27, R46.1, R47.1
/Driver_MCF8316A/D1_A: IC9.13, IC9.14, J11.6, J11.7
/Driver_MCF8316A/D1_B: IC9.16, IC9.17, J11.8, J11.9
/Driver_MCF8316A/D1_C: IC9.19, IC9.20, J11.10, J11.11
/Driver_MCF8316A/VBK: C18.1, D3.2, D4.2, D5.2, IC9.3, R42.2
/Power Input & Filter/+12V_in: C26.1, C27.1, C28.1, C29.1, C36.1, IC10.1, J10.2, L2.1
/Power_Monitoring/12v_Power: J4.1, J4.5, R33.1, R34.2, R36.2
/SCL_Buspro: IC3.1, IC3.3, IC5.1, IC5.3, J1.12, R6.2, R18.2, R26.2, TP3.1
/SCL_D1: IC9.31, J1.4
/SCL_D2: J1.8, J2.1
/SDA_Buspro: IC2.1, IC2.3, IC4.1, IC4.3, J1.10, R5.2, R17.2, R25.2, TP2.1
/SDA_D1: IC9.30, J1.2
/SDA_D2: J1.6, J2.3
/ToADC_Sense1: IC8.1, J1.14
/ToADC_Sense2: IC8.9, J1.16
/scl_power1: IC3.4, IC3.6, IC7.5, R6.1, R11.2, R12.1, TP5.1
/scl_power2: IC5.4, IC5.6, IC6.5, R18.1, R23.2, R24.1, TP7.1
/sda_power1: IC2.4, IC2.6, IC7.4, R5.1, R9.2, R10.1, TP4.1
/sda_power2: IC4.4, IC4.6, IC6.4, R17.1, R21.2, R22.1, TP6.1
D1_Alarm1: IC9.39, J9.5, R51.2, R54.2
D1_Alarm2: IC9.40, J9.7, R52.2, R55.2
D1_EXT_CLK: IC9.33, J9.4
D1_EXT_WD: IC9.32, J9.6
D1_FG: IC9.29, J9.8, R56.2
D1_SOX: IC9.36, J9.2
D1_X1: IC9.37, J9.1, R48.2
D1_X2: IC9.38, J9.3, R49.1
GND: C1.1, C2.2, C3.1, C7.2, C8.2, C9.2, C10.2, C11.2, C12.2, C17.2, C18.2, C19.2, C23.2, C24.2, C25.2, C35.1, C37.1, H1.1, H2.1, H3.1, H4.1, IC1.5, IC1.8, IC6.2, IC6.7, IC7.1, IC7.2, IC7.7, IC8.4, IC8.5, IC8.6, IC9.2, IC9.4, IC9.26, IC9.41, IC10.12, J1.19, J3.5, J3.MP1, J3.MP2, J11.5, J11.MP1, J11.MP2, J13.2, Q1.1, Q1.4, Q2.1, Q2.4, Q3.1, Q3.4, Q4.1, Q4.4, R43.1, R44.2, R45.2, R50.2, R57.2
GNDPWR: C6.2, C21.2, C26.2, C27.2, C28.2, C29.2, C30.2, C31.2, C32.2, C33.2, C34.2, C36.2, IC1.15, IC1.16, IC1.25, IC9.12, IC9.15, IC9.18, IC10.2, IC10.3, J10.1, R53.2, R57.1
unnamed: C1.2, IC1.6, L1.1
unnamed: C2.1, IC1.7
unnamed: C3.2, IC1.9
unnamed: C4.1, IC1.2
unnamed: C4.2, IC1.3
unnamed: C5.2, IC1.1
unnamed: C7.1, Q1.2, R10.2
unnamed: C8.1, Q2.2, R12.2
unnamed: C9.1, Q3.2, R22.2
unnamed: C10.1, Q4.2, R24.2
unnamed: C13.1, IC6.10, R29.2
unnamed: C13.2, IC6.9, R30.2
unnamed: C19.1, IC9.1
unnamed: C20.1, IC9.8
unnamed: C22.1, IC9.6
unnamed: C22.2, IC9.7
unnamed: C24.1, R48.1, Y1.1
unnamed: C25.1, R49.2, Y1.2
unnamed: D1.2, R37.2
unnamed: D2.2, R38.2
unnamed: D3.1, R50.1
unnamed: D4.1, R51.1
unnamed: D5.1, R52.1
unnamed: D6.1, R53.1
unnamed: IC1.4, L1.2
unnamed: IC2.2, R3.1
unnamed: IC2.5, Q1.3, R1.2, R3.2
unnamed: IC3.2, R4.1
unnamed: IC3.5, Q2.3, R2.2, R4.2
unnamed: IC4.2, R15.1
unnamed: IC4.5, Q3.3, R13.2, R15.2
unnamed: IC5.2, R16.1
unnamed: IC5.5, Q4.3, R14.2, R16.2
unnamed: IC9.5, R42.1
unnamed: IC9.22, IC9.23, IC9.24, IC9.25, R43.2
unnamed: J3.1, J8.4
unnamed: J3.2, J8.3
unnamed: J3.3, J8.2
unnamed: J3.4, J8.1
unnamed: J5.1, R40.1, R41.2
unnamed: J6.1, R46.2
unnamed: J6.3, R44.1
unnamed: J7.1, R47.2
unnamed: J7.3, R45.1
unnamed: J11.1, J12.4
unnamed: J11.2, J12.3
unnamed: J11.3, J12.2
unnamed: J11.4, J12.1
unnamed: Q1.5, Q1.6, R7.2
unnamed: Q2.5, Q2.6, R8.2
unnamed: Q3.5, Q3.6, R19.2
unnamed: Q4.5, Q4.6, R20.2
Rsense+: C16.1, IC8.3, R39.2
Rsense-: C16.2, IC8.2, R40.2
RsenseA_IN+: C14.1, IC7.10, R32.2
RsenseA_IN-: C14.2, IC7.9, R33.2
RsenseB_IN+: C15.1, IC8.8, R35.1
RsenseB_IN-: C15.2, IC8.7, R36.1

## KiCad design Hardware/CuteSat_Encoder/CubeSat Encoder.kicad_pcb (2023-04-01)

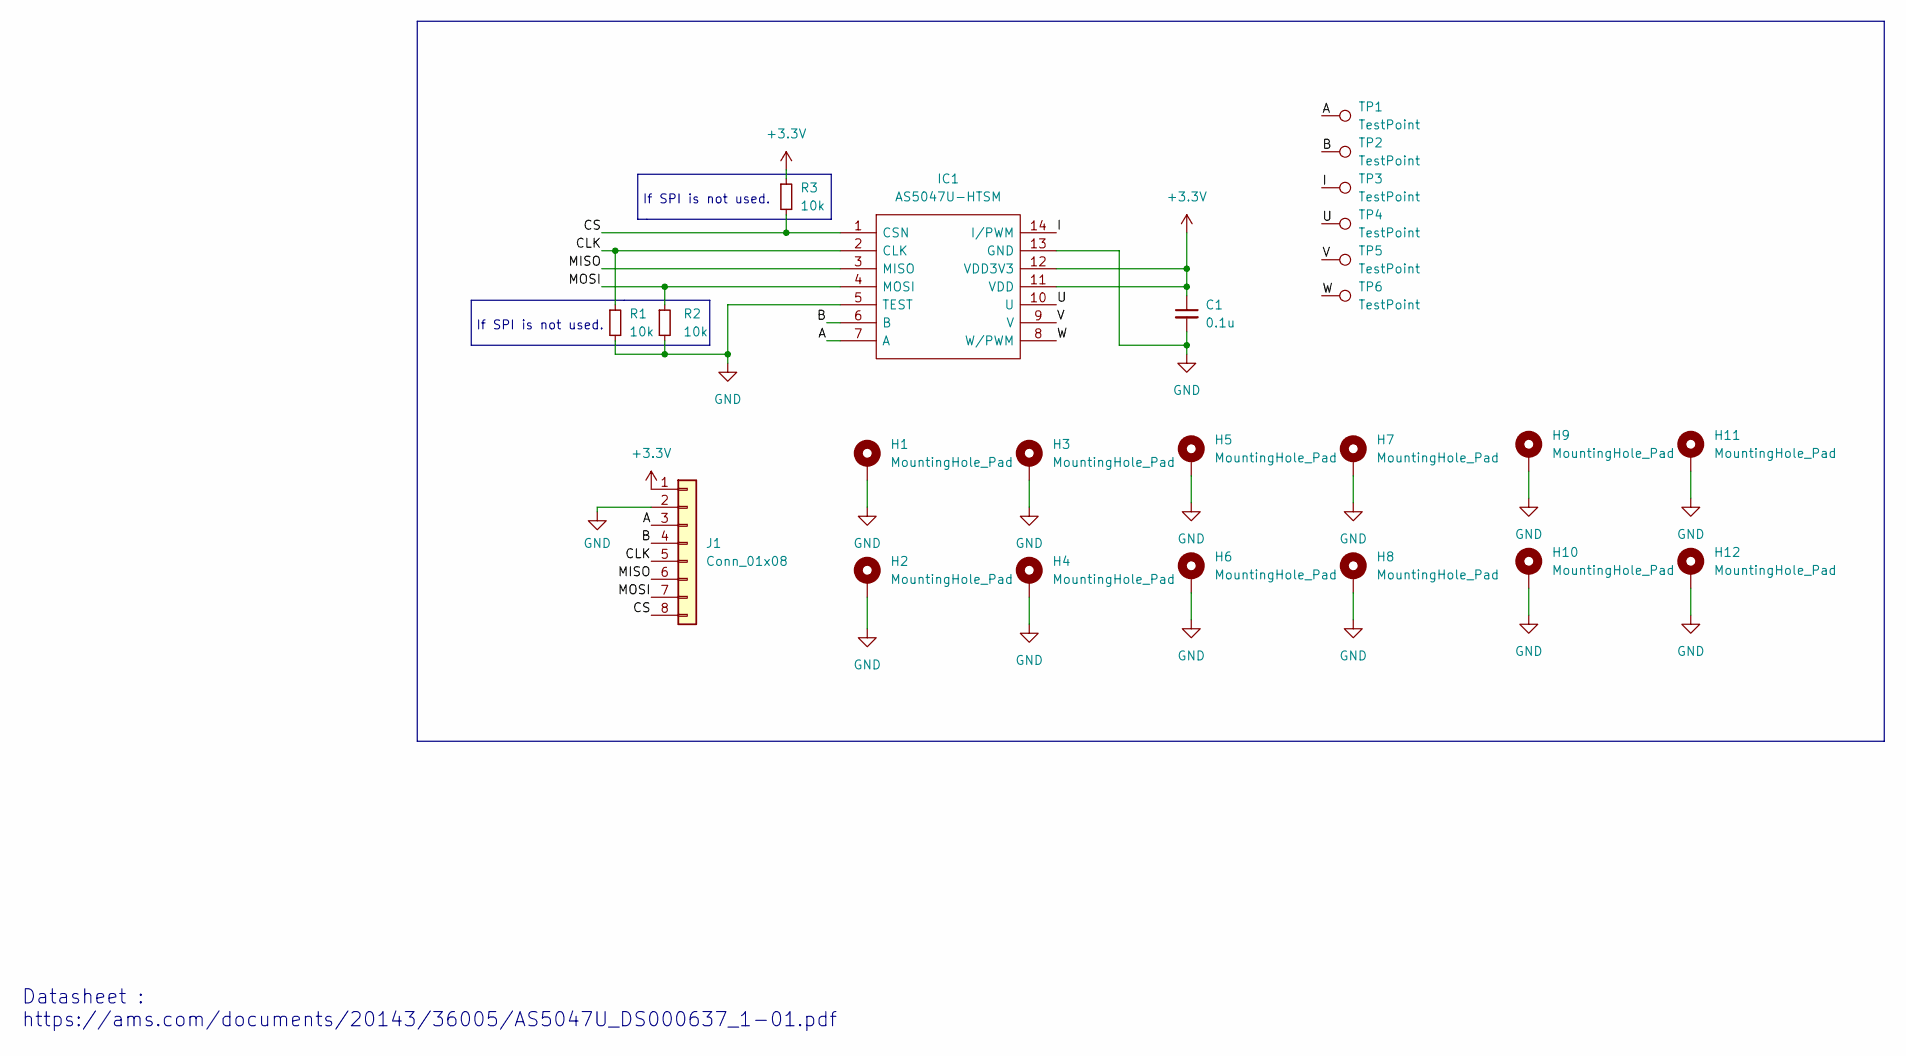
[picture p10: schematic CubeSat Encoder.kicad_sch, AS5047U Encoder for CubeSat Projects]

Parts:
C1: 0.1u; C_0603_1608Metric_Pad1.08x0.95mm_HandSolder
H1, H2, H3, H4, H5, H6, H7, H8, H9, H10, H11, H12: MountingHole_Pad; MountingHole_2.2mm_M2_Pad_Via
IC1: AS5047U-HTSM; SOP65P640X120-14N; Manufacturer_Part_Number AS5047U-HTSM; Mouser Part Number 985-AS5047U-HTSM
J1: Conn_01x08; JST_XH_S8B-XH-A-1_1x08_P2.50mm_Horizontal
R1, R2, R3: 10k; R_0603_1608Metric_Pad0.98x0.95mm_HandSolder
TP1, TP2, TP3, TP4, TP5, TP6: TestPoint; TestPoint_Pad_1.0x1.0mm

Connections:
+3V3: C1.1, IC1.11 (VDD), IC1.12 (VDD3V3), J1.1, R3.1
/A: IC1.7 (A), J1.3, TP1.1
/B: IC1.6 (B), J1.4, TP2.1
/CLK: IC1.2 (CLK), J1.5, R1.1
/CS: IC1.1 (CSN), J1.8, R3.2
/I: IC1.14 (I/PWM), TP3.1
/MISO: IC1.3 (MISO), J1.6
/MOSI: IC1.4 (MOSI), J1.7, R2.1
/U: IC1.10 (U), TP4.1
/V: IC1.9 (V), TP5.1
/W: IC1.8 (W/PWM), TP6.1
GND: C1.2, H1.1, H2.1, H3.1, H4.1, H5.1, H6.1, H7.1, H8.1, H9.1, H10.1, H11.1, H12.1, IC1.5 (TEST), IC1.13 (GND), J1.2, R1.2, R2.2

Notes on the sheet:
If SPI is not used.
Datasheet : https://ams.com/documents/20143/36005/AS5047U_DS000637_1-01.pdf

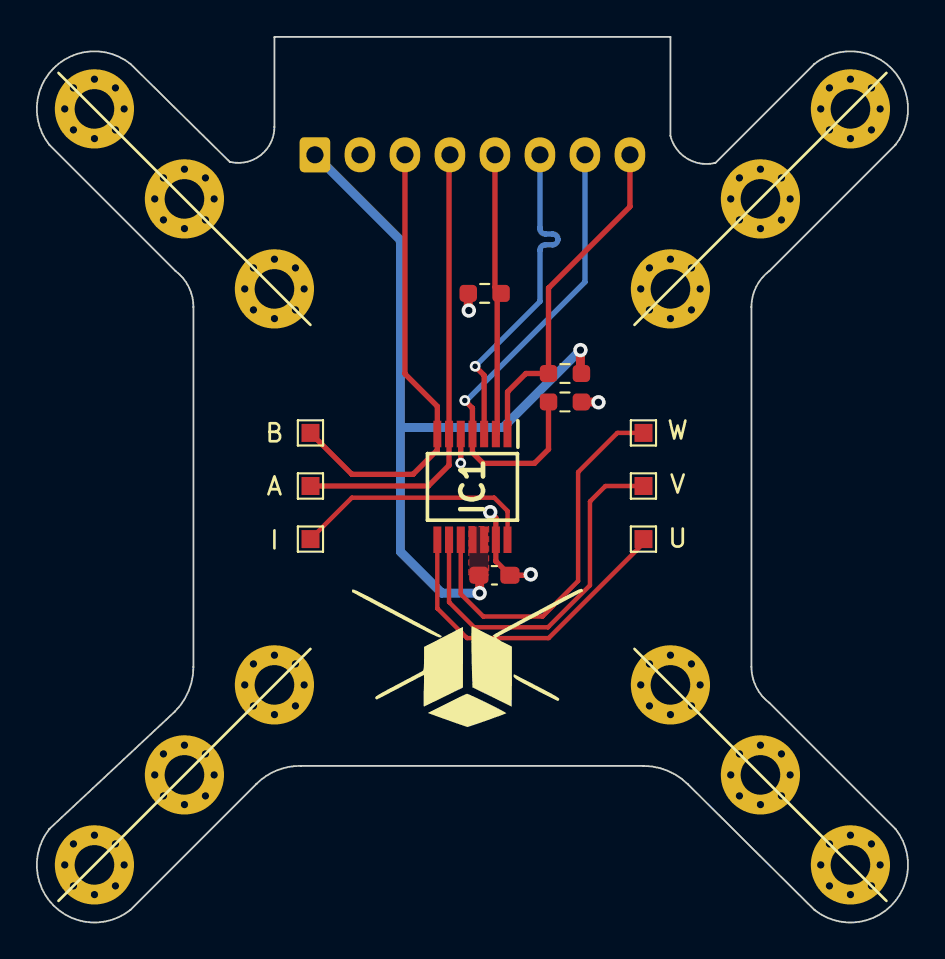
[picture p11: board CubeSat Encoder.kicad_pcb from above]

Board: 4 copper layers, 48.4 x 49.2 mm, 24 parts (1 on the bottom side), 12 nets.

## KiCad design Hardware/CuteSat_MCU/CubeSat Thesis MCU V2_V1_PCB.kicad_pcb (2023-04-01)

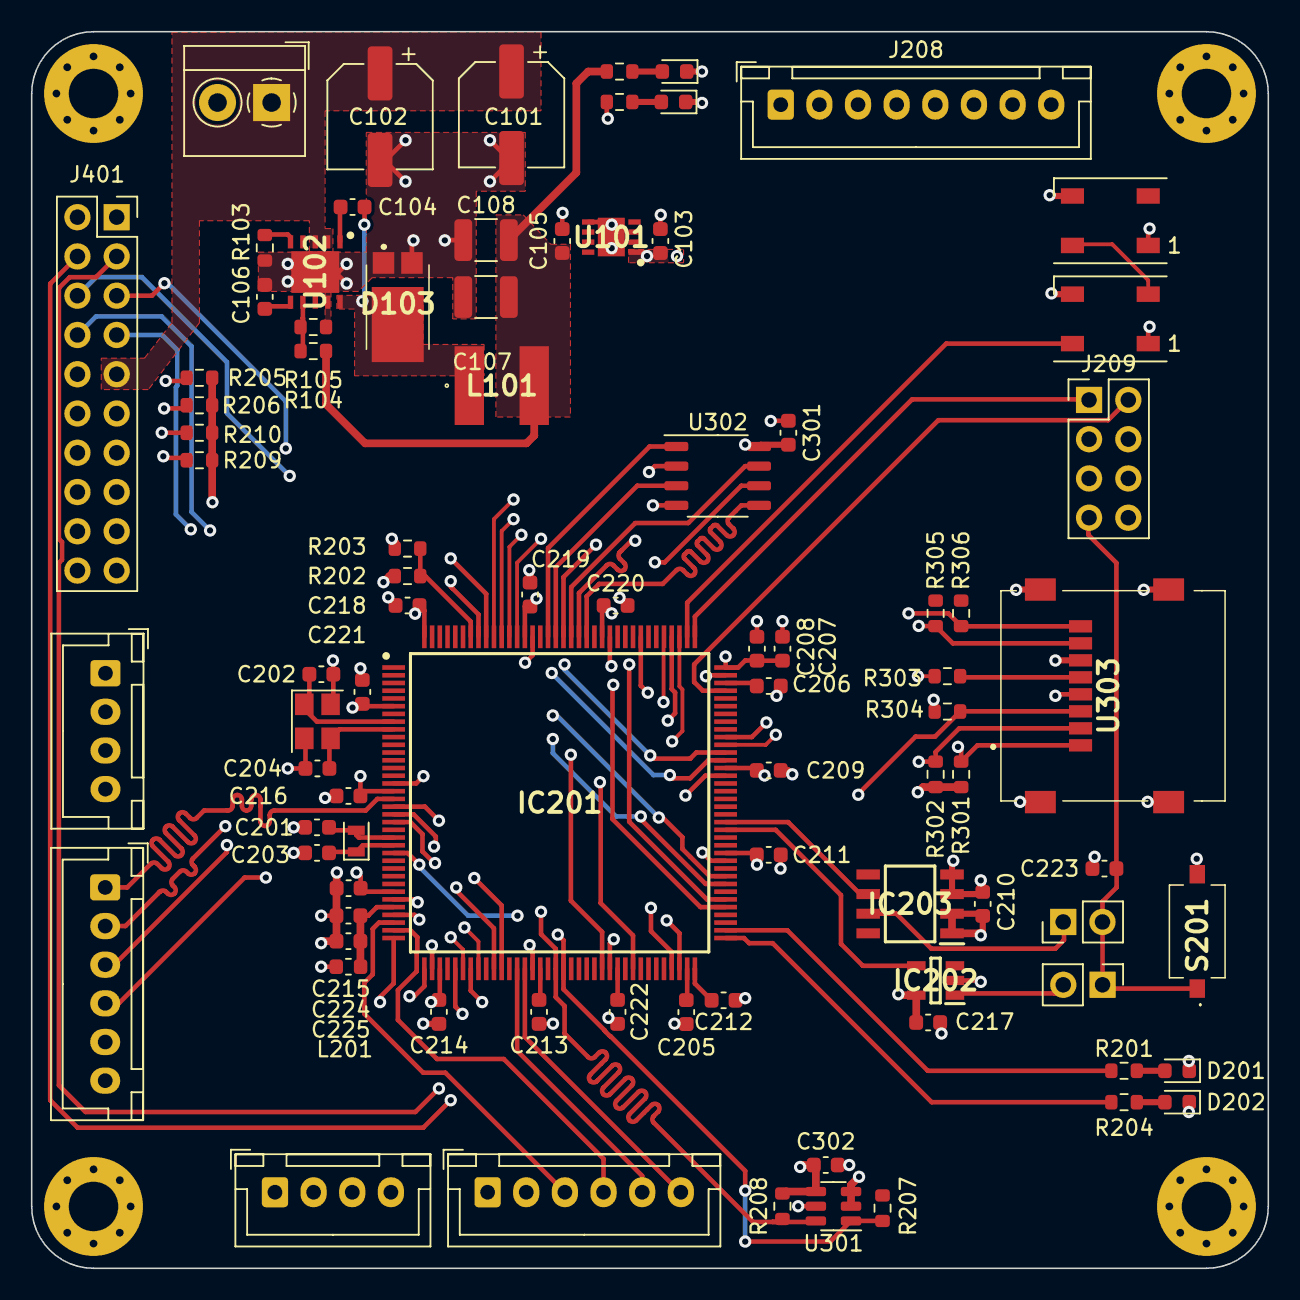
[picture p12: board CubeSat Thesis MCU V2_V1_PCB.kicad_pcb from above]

Board: 4 copper layers, 80.0 x 80.0 mm, 90 parts (0 on the bottom side), 79 nets.

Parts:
C101: 100u; CP_Elec_6.3x5.4
C102: 47u; CP_Elec_6.3x5.4
C103: 1uF; C_0603_1608Metric
C104, C208, C209, C210, C211, C212, C213, C214, C215, C216, C217, C218, C219, C220, C221, C222, C223, C224, C301, C302: 0.1u; C_0603_1608Metric
C105: 10uF; C_0603_1608Metric
C106: 4.7n; C_0603_1608Metric
C107, C108: 47u; C_1210_3225Metric
C201, C203: 4p; C_0603_1608Metric
C202, C204: 10p; C_0603_1608Metric
C205, C206: 2.2u; C_0603_1608Metric
C207: 4.7u; C_0603_1608Metric
C225: 1u; C_0603_1608Metric
D101, D102, D201, D202: GREEN; LED_0603_1608Metric
D103: SDT5100LP5-13; SDT5100LP513
D203, D204: WS2812B; LED_WS2812B_PLCC4_5.0x5.0mm_P3.2mm
H101, H102, H103, H104: M3; MountingHole_3.2mm_M3_Pad_Via
IC201: STM32H743ZIT6; QFP50P2200X2200X160-144N
IC202: TPS3828-50QDBVRG4Q; SOT95P280X145-5N
IC203: MAX706RESA+T; SOIC127P600X175-8N
J101: Terminal Block 2mm 01x02; TerminalBlock_4Ucon_1x02_P3.50mm_Horizontal
J201: WDT2_EN_JUMPER; PinHeader_1x02_P2.54mm_Vertical
J202: UART_Conn; JST_XH_B4B-XH-A_1x04_P2.50mm_Vertical
J203: I2C_Conn_1; JST_XH_B4B-XH-A_1x04_P2.50mm_Vertical
J204: SPI_Conn; JST_XH_B6B-XH-A_1x06_P2.50mm_Vertical
J205: GPIO_Conn; JST_XH_B6B-XH-A_1x06_P2.50mm_Vertical
J206: WDT1_EN_JUMPER; PinHeader_1x02_P2.54mm_Vertical
J208: Encoder_Conn; JST_XH_B8B-XH-A_1x08_P2.50mm_Vertical
J209: Programming Port; PinHeader_2x04_P2.54mm_Vertical
J401: Peripheral Connector; PinSocket_2x10_P2.54mm_Vertical
L101: 6.8u; VLS6045
L201: 47n; L_0603_1608Metric
R101, R102, R201, R204: 470; R_0603_1608Metric
R103: 23.4k; R_0603_1608Metric
R104, R203: 100k; R_0603_1608Metric
R105: 17.8k; R_0603_1608Metric
R202: 0; R_0603_1608Metric
R205, R206, R207, R208, R209, R210, R301, R302, R304, R305, R306: 10k; R_0603_1608Metric
R303: 22; R_0603_1608Metric
S201: TS-1101-C-W; TS1101CW
U101: TPS78511QWDRBRQ1; SON65P300X300X100-9N-D
U102: LMR14030QDPRRQ1; SON80P400X400X80-11N-D
U301: TMP100; SOT-23-6
U302: MB85RS64; SSOP-8_3.9x5.05mm_P1.27mm
U303: 47219-2001; 472192001
Y201: 32.768 kHz; Crystal_SMD_2012-2Pin_2.0x1.2mm
Y202: 16 MHz; Crystal_SMD_3225-4Pin_3.2x2.5mm

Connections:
+3.3VA: C224.1, C225.1, IC201.32 (VREF+), L201.2
+3V3: C103.1, C207.1, C208.1, C209.1, C210.1, C211.1, C212.1, C213.1, C214.1, C215.1, C216.1, C217.1, C218.1, C219.1, C220.1, C221.1, C222.1, C301.1, C302.1, D203.1 (VDD), D204.1 (VDD), IC201.6 (VBAT), IC201.17 (VDD_1), IC201.30 (VDD_2), IC201.39 (VDD_3), IC201.52 (VDD_4), IC201.62 (VDD_5), IC201.72 (VDD_6), IC201.84 (VDD_7), IC201.95 (VDD33USB), IC201.108 (VDD_8), IC201.121 (VDD_9), IC201.131 (VDD_10), IC201.143 (PDR_ON), IC201.144 (VDD_11), IC202.5 (VDD), IC203.1 (~MR), IC203.2 (VCC), J202.1, J203.1, J204.6, J205.1, J208.1, J209.8, J401.19, L201.1, R101.1, R202.1, R205.1, R206.1, R207.1, R208.1, R209.1, R210.1, R301.1, R302.1, R304.1, R305.1, R306.1, U101.1 (OUT), U301.4 (V+), U302.8 (VDD), U303.4 (VDD)
+5V: C105.1, C107.1, C108.1, L101.2, R102.1, R104.1, U101.7 (EN), U101.8 (IN)
+12V: C101.1, C102.1, J101.1, J401.9, U102.2 (VIN_1), U102.3 (VIN_2)
/LMR14030_SW: C104.2, D103.3 (K), L101.1, U102.10 (SW)
/Memory and Sensor/FRAM_CS: IC201.128 (PG13), U302.1 (~CS)
/Memory and Sensor/FRAM_HOLD: IC201.125 (PG10), U302.7 (~HOLD)
/Memory and Sensor/FRAM_MISO: IC201.124 (PG9), U302.2 (SO)
/Memory and Sensor/FRAM_MOSI: IC201.123 (PD7), U302.5 (SI)
/Memory and Sensor/FRAM_SCK: IC201.126 (PG11), U302.6 (SCK)
/Memory and Sensor/FRAM_WP: IC201.127 (PG12), U302.3 (~WP)
/Memory and Sensor/SDIO_CLK: IC201.113 (PC12), R303.1
/Memory and Sensor/SDIO_CMD: IC201.116 (PD2), R304.2, U303.3 (CMD)
/Memory and Sensor/SDIO_D0: IC201.98 (PC8), R305.2, U303.7 (DAT0)
/Memory and Sensor/SDIO_D1: IC201.99 (PC9), R306.2, U303.8 (DAT1)
/Memory and Sensor/SDIO_D2: IC201.111 (PC10), R301.2, U303.1 (DAT2)
/Memory and Sensor/SDIO_D3: IC201.112 (PC11), R302.2, U303.2 (CD/DAT3)
/Microcontroller/ADC_Sense1: IC201.42 (PA6), J401.17
/Microcontroller/ADC_Sense2: IC201.44 (PC4), J401.18
/Microcontroller/ALERT_INA238_1: IC201.46 (PB0), J401.7
/Microcontroller/ALERT_INA238_2: IC201.47 (PB1), J401.8
/Microcontroller/BOOT0: IC201.138 (BOOT0), R202.2, R203.1
/Microcontroller/D1_BREAK: IC201.43 (PA7), J401.4
/Microcontroller/D1_DIR: IC201.97 (PC7), J401.2
/Microcontroller/D1_DRVOFF: IC201.41 (PA5), J401.3
/Microcontroller/D1_SPEED: IC201.96 (PC6), J401.1
/Microcontroller/D2_DIR: IC201.80 (PD11), J401.6
/Microcontroller/D2_SPEED: IC201.81 (PD12), J401.5
/Microcontroller/HSE_IN: C202.1, IC201.8 (PC14-OSC32_IN), Y202.1
/Microcontroller/HSE_OUT: C204.1, IC201.9 (PC15-OSC32_OUT), Y202.3
/Microcontroller/I2C1_SCL: IC201.136 (PB6), J401.12, R205.2
/Microcontroller/I2C1_SDA: IC201.137 (PB7), J401.11, R206.2
/Microcontroller/I2C2_SCL: IC201.69 (PB10), J401.14, R210.2
/Microcontroller/I2C2_SDA: IC201.70 (PB11), J401.13, R209.2
/Microcontroller/I2C4_SCL: IC201.54 (PF14), J203.3, J401.15, R208.2, U301.6 (SDA)
/Microcontroller/I2C4_SDA: IC201.55 (PF15), J203.4, J401.16, R207.2, U301.1 (SCL)
/Microcontroller/LED1: IC201.74 (PB13), R201.1
/Microcontroller/LED2: IC201.73 (PB12), R204.1
/Microcontroller/LSE_IN: C201.1, IC201.23 (PH0-OSC_IN), Y201.2
/Microcontroller/LSE_OUT: C203.1, IC201.24 (PH1-OSC_OUT), Y201.1
/Microcontroller/NRST: C223.1, IC201.25 (NRST), J201.1, J206.2, J209.7, S201.1 (COM)
/Microcontroller/PA0: IC201.34 (PA0), J205.3
/Microcontroller/PA1: IC201.35 (PA1), J205.4
/Microcontroller/PF11: IC201.49 (PF11), J205.5
/Microcontroller/PF12: IC201.50 (PF12), J205.6
/Microcontroller/PWM_LED: D203.4 (DIN), IC201.110 (PA15)
/Microcontroller/SPI3_CS: IC201.132 (PG15), J208.6
/Microcontroller/SPI3_MISO: IC201.134 (PB4), J208.4
/Microcontroller/SPI3_MOSI: IC201.135 (PB5), J208.3
/Microcontroller/SPI3_SCK: IC201.133 (PB3), J208.5
/Microcontroller/SPI5_CS: IC201.18 (PF6), J204.1
/Microcontroller/SPI5_MISO: IC201.20 (PF8), J204.3
/Microcontroller/SPI5_MOSI: IC201.21 (PF9), J204.4
/Microcontroller/SPI5_SCK: IC201.19 (PF7), J204.2
/Microcontroller/SWCLK: IC201.109 (PA14), J209.1
/Microcontroller/SWDIO: IC201.105 (PA13), J209.2
/Microcontroller/TIM1_CH1: IC201.60 (PE9), J208.7
/Microcontroller/TIM1_CH2: IC201.64 (PE11), J208.8
/Microcontroller/UART2_RX: IC201.37 (PA3), J202.4
/Microcontroller/UART2_TX: IC201.36 (PA2), J202.3
/Microcontroller/UART3_RX: IC201.78 (PD9), J209.3
/Microcontroller/UART3_TX: IC201.77 (PD8), J209.4
/Microcontroller/WDI1: IC201.88 (PG3), IC203.6 (WDI)
/Microcontroller/WDI2: IC201.87 (PG2), IC202.4 (WDI)
GND: C101.2, C102.2, C103.2, C105.2, C106.2, C107.2, C108.2, C201.2, C202.2, C203.2, C204.2, C205.2, C206.2, C207.2, C208.2, C209.2, C210.2, C211.2, C212.2, C213.2, C214.2, C215.2, C216.2, C217.2, C218.2, C219.2, C220.2, C221.2, C222.2, C223.2, C224.2, C225.2, C301.2, C302.2, D101.1 (K), D102.1 (K), D103.1 (A), D103.2 (A), D201.1 (K), D202.1 (K), D203.3 (VSS), D204.3 (VSS), H101.1, H102.1, H103.1, H104.1, IC201.16 (VSS_1), IC201.31 (VSSA), IC201.33 (VDDA), IC201.38 (VSS_2), IC201.51 (VSS_3), IC201.61 (VSS_4), IC201.83 (VSS_5), IC201.94 (VSS_6), IC201.107 (VSS_7), IC201.120 (VSS_8), IC201.130 (VSS_9), IC202.2 (GND), IC203.3 (GND), IC203.4 (PFI), J101.2, J202.2, J203.2, J204.5, J205.2, J208.2, J209.6, J401.10, R103.2, R105.2, R203.2, S201.2 (NO), U101.5 (GND), U101.9 (EP), U102.9 (GND), U102.11 (EP), U301.2 (GND), U301.3 (ADD1), U301.5 (ADD0), U302.4 (GND), U303.6 (VSS), U303.9 (GND_1), U303.10 (GND_2), U303.11 (GND_3), U303.12 (GND_4), Y202.2, Y202.4
unnamed: C104.1, U102.1 (BOOT)
unnamed: C106.1, U102.6 (SS)
unnamed: C205.1, IC201.71 (VCAP_1)
unnamed: C206.1, IC201.106 (VCAP_2)
unnamed: D101.2 (A), R101.2
unnamed: D102.2 (A), R102.2
unnamed: D201.2 (A), R201.2
unnamed: D202.2 (A), R204.2
unnamed: D203.2 (DOUT), D204.4 (DIN)
unnamed: IC202.1 (~RESET), J201.2
unnamed: IC203.7 (~RESET), J206.1
unnamed: R103.1, U102.5 (RT/SYNC)
unnamed: R104.2, R105.1, U102.7 (FB)
unnamed: R303.2, U303.5 (CLK)

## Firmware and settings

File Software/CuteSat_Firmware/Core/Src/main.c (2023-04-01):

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
/* Includes ------------------------------------------------------------------*/
#include "main.h"
#include "adc.h"
#include "crc.h"
#include "dma.h"
#include "fatfs.h"
#include "i2c.h"
#include "rtc.h"
#include "sdmmc.h"
#include "spi.h"
#include "tim.h"
#include "usart.h"
#include "usb_device.h"
#include "gpio.h"

/* USER CODE BEGIN Includes */
#include <string.h>
#include <math.h>
#include <Library/Logging.h>
#include <Library/FRAM.h>
#include <Library/TMP75.h>
#include <Library/INA238.h>
#include <Library/AS5047U.h>
#include <Library/Neopixel.h>
#include <Library/KalmanFilter.h>
#include <Library/EDAC.h>
#include <Library/Utils.h>
#include <Library/DRV10975.h>
#include <usbd_cdc_if.h>
/* USER CODE END Includes */

/* USER CODE BEGIN PD */
#define KALMAN_Q 5000
#define KALMAN_R 0.1
/* USER CODE END PD */


/* USER CODE BEGIN PV */
NeopixelParameter Neopixel;
AS5047U Encoder;
INA238 Current_Sensor_System;
INA238 Current_Sensor_Motor;
FRAM Fram;
DRV10975 Sin_Driver;

KalmanFilter KF_Motor;

float LDO_temp = 0.0;
int64_t filtered_motor_pos = 0;
int64_t filtered_motor_speed = 0;

uint16_t adc_in[2] = { 0 };
uint16_t adc_in2[2] = { 0 };

uint8_t d1_voltage = 0;
uint8_t fram_status = 0;
uint8_t d1_dir = 1;
uint8_t test_in[9] = { 0 };
int32_t sin_speed = 511;

uint64_t _micro = 0;
uint8_t final_ans[8] = { 0 };
uint8_t speed_change_trigger = 0;
RTC_TimeTypeDef gTime;

float SpeedBuffer1Sent[3000] = {0};
float SpeedBuffer2Sent[3000] = {0};
uint16_t Count2Sent = 0;
uint16_t CountStart = 0;

double motor_pos = 0;

/* USER CODE END PV */

void SystemClock_Config(void);
/* USER CODE BEGIN PFP */
#ifdef __GNUC__
/* With GCC, small printf (option LD Linker->Libraries->Small printf
 set to 'Yes') calls __io_putchar() */
#define PUTCHAR_PROTOTYPE int __io_putchar(int ch)
#else
#define PUTCHAR_PROTOTYPE int fputc(int ch, FILE *f)
#endif /* __GNUC__ */
/* USER CODE END PFP */

/* USER CODE BEGIN 0 */
void Watchog_Timer_Trigger();
void Read_Power_Monitoring_Data();
void Read_Encoder();
void Control_Loop();
void Device_Init();
void Store_Config();
void Read_Config();
void Read_Driver_Param();
void Test_Fram();
void get_time();
/* USER CODE END 0 */

/**
  * @brief  The application entry point.
  * @retval int
  */
int main(void)
{
  /* MCU Configuration--------------------------------------------------------*/

  /* Reset of all peripherals, Initializes the Flash interface and the Systick. */
  HAL_Init();

  /* Configure the system clock */
  SystemClock_Config();

  /* Initialize all configured peripherals */
  MX_GPIO_Init();
  MX_SDMMC1_SD_Init();
  MX_FATFS_Init();
  MX_DMA_Init();
  MX_TIM2_Init();
  MX_USART3_UART_Init();
  MX_SPI2_Init();
  MX_I2C1_Init();
  MX_I2C4_Init();
  MX_SPI1_Init();
  MX_SPI6_Init();
  MX_TIM1_Init();
  MX_TIM3_Init();
  MX_TIM15_Init();
  MX_TIM17_Init();
  MX_USART2_UART_Init();
  MX_CRC_Init();
  MX_TIM6_Init();
  MX_RTC_Init();
  MX_I2C2_Init();
  MX_TIM4_Init();
  MX_ADC1_Init();
  MX_USB_DEVICE_Init();
  MX_TIM7_Init();
  /* USER CODE BEGIN 2 */
	HAL_TIM_Base_Start_IT(&htim7);
	Watchog_Timer_Trigger();
	Device_Init();
	DRV10975_I2C_Set_Speed(&Sin_Driver, 0, 1);
	Test_Fram();
	while(1);
	uwTick = 0;
	uint32_t timestamp_1 = HAL_GetTick();
	uint32_t timestamp_2 = HAL_GetTick();
	uint32_t timestamp_3 = HAL_GetTick();
	uint32_t timestamp_4 = HAL_GetTick();
	uint8_t debug_msg[100] = "";
  /* USER CODE END 2 */

  /* Infinite loop */
  /* USER CODE BEGIN WHILE */
	while (1) {
		Read_Encoder();
		if (HAL_GetTick() - timestamp_1 >= 10) {
			timestamp_1 = HAL_GetTick();
			Read_Driver_Param();
			CountStart++;
			if (CountStart >= 500) {
				if (Count2Sent < 3000) {
					if (Count2Sent == 0) {
						DRV10975_I2C_Set_Speed(&Sin_Driver, sin_speed, d1_dir);
					}
					else if (Count2Sent == 1500){
						DRV10975_I2C_Set_Speed(&Sin_Driver, sin_speed, 0);
					}
					SpeedBuffer1Sent[Count2Sent] =
							(float) Sin_Driver.motor_speed;
					SpeedBuffer2Sent[Count2Sent] = (float) (4 * KF_Motor.x2
							/ (6.28318530718));
					Count2Sent++;
				} else {
					if (Count2Sent == 3000) {
						DRV10975_I2C_Set_Speed(&Sin_Driver, 0, d1_dir);
						for (int i = 0; i < 3000; i++) {
							printf("%f %f \n", SpeedBuffer1Sent[i],
									SpeedBuffer2Sent[i]);
						}
					}
					Count2Sent = 0;
					CountStart = 0;
				}
				if (speed_change_trigger) {
					DRV10975_I2C_Set_Speed(&Sin_Driver, sin_speed, d1_dir);
				}
			}
		}
		if (HAL_GetTick() - timestamp_2 >= 100) {
			timestamp_2 = HAL_GetTick();
			Read_Power_Monitoring_Data();
		}
		if (HAL_GetTick() - timestamp_3 >= 1) {
			timestamp_3 = HAL_GetTick();
			Control_Loop();
		}
		if (HAL_GetTick() - timestamp_4 >= 10000) {
			timestamp_4 = HAL_GetTick();
			sprintf((char *)debug_msg, "ldo temp is : %f", LDO_temp);
			SD_Card_Write_Log(LOG_DEBUG, debug_msg, strlen((char *) debug_msg));
			sprintf((char *)debug_msg, "power consumption of system : %f", Current_Sensor_System.power);
			SD_Card_Write_Log(LOG_DEBUG, debug_msg, strlen((char *) debug_msg));
			sprintf((char *)debug_msg, "power consumption of motor and driver : %f", Current_Sensor_Motor.power);
			SD_Card_Write_Log(LOG_DEBUG, debug_msg, strlen((char *) debug_msg));
		}
		HAL_RTC_GetTime(&hrtc, &gTime, RTC_FORMAT_BIN);
		Watchog_Timer_Trigger();

//	  SD_Card_Write_Log();
    /* USER CODE END WHILE */

    /* USER CODE BEGIN 3 */
	}
  /* USER CODE END 3 */
}

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
/* USER CODE BEGIN 4 */


void Read_Power_Monitoring_Data() {
	TMP75_Read_TempCelsius(&LDO_temp);
	INA238_read_all(&Current_Sensor_Motor);
	INA238_read_all(&Current_Sensor_System);
}

void Read_Encoder() {
	AS5047U_Position_Highspeed_Read(&Encoder, 0);
}

void Read_Driver_Param() {
	DRV10975_Read_Voltage(&Sin_Driver);
	DRV10975_Read_Kt(&Sin_Driver);
	DRV10975_Read_Period(&Sin_Driver);
	DRV10975_Read_Speed(&Sin_Driver);
	DRV10975_Read_Current(&Sin_Driver);
}

void Control_Loop() {
	static uint16_t enc_pos = 0;
	static uint16_t prev_enc_pos = 0;

	enc_pos = Encoder.Position;
	motor_pos += (Unwrap(enc_pos, prev_enc_pos) * (2 * M_PI / 16384.0)); //0.087890625 = (360 / 4096)
	prev_enc_pos = enc_pos;
	KalmanFilter_Update(&KF_Motor, motor_pos);
	filtered_motor_pos = KF_Motor.x1;
	filtered_motor_speed = KF_Motor.x2;
}

void Device_Init() {
	HAL_GPIO_WritePin(LED1_GPIO_Port, LED1_Pin, 1); // indicate that mcu still alive :>

	uint8_t initialize_msg[25] = "MCU still alive :>";
	SD_Card_Write_Log(LOG_INFO, initialize_msg, strlen((char *) initialize_msg));

	KalmanFilter_Init(&KF_Motor, 0, 0, 1, 0, 0, 1, KALMAN_R, KALMAN_Q, 0.001);

	HAL_GPIO_WritePin(FRAM_WP_GPIO_Port, FRAM_WP_Pin, GPIO_PIN_RESET);
	HAL_GPIO_WritePin(FRAM_HOLD_GPIO_Port, FRAM_HOLD_Pin, GPIO_PIN_SET);
	FRAM_Initialise(&Fram, &hspi2, FRAM_CS_GPIO_Port, FRAM_CS_Pin);
	AS5047U_init(&Encoder, &hspi1, SPI1_CS_GPIO_Port, &hcrc, SPI1_CS_Pin, 0);

	DRV10975_Init(&Sin_Driver, &hi2c2, &htim17, TIM_CHANNEL_1, D1_DIR_GPIO_Port,
	D1_DIR_Pin);
	DRV10975_Config(&Sin_Driver);
	//Motor Driver Current Sensor
	INA238_init(&Current_Sensor_Motor, &hi2c4, 0x80);
	INA238_reset(&Current_Sensor_Motor);
	INA238_set_mode(&Current_Sensor_Motor, 0x0F);
	INA238_calibrate(&Current_Sensor_Motor, 0, 0.05);

	//System Current Sensor
	INA238_init(&Current_Sensor_System, &hi2c4, 0x88);
	INA238_reset(&Current_Sensor_System);
	INA238_set_mode(&Current_Sensor_System, 0x0F);
	INA238_calibrate(&Current_Sensor_System, 1, 0.1);

	Neopixel_Init(&Neopixel, &htim2);
}

void Watchog_Timer_Trigger() {
	// External WD Trigger
	HAL_GPIO_TogglePin(WDI1_GPIO_Port, WDI1_Pin);
	HAL_GPIO_TogglePin(WDI2_GPIO_Port, WDI2_Pin);
	// Internal WD
//	HAL_IWDG_Refresh(&hiwdg1);
}

void Test_Fram() {
	float read_first_data = 0;
	uint32_t read_second_data = 0;
	uint8_t test[8] = {0x42,0xf6,0xe6,0x66,0x00,0x00,0x1a,0x85};
	uint8_t before_flip[9] = {0};
//	uint8_t after_flip[9] = { 0 };
	hamming7264_encode(test, before_flip);

//	// declare data
	float write_first_data = 123.45;
	uint32_t write_second_data = 6789;

	printf("This is the data that we want to store. %f, %u\n", write_first_data,
			(unsigned int) write_second_data);

	//encode data and write to fram
	FRAM_Encode_Write_Block(&Fram, 0, (uint32_t*) &write_first_data,
			&write_second_data);

//	uint8_t read_data = 0;
//	FRAM_Seq_Read(&Fram, 0, before_flip, 9);

	printf("This is the data after we encode.            0x");
	for (int i = 0; i < 9; i++) {
		printf("%x", before_flip[i]);
	}
	printf("\n");
	// read -> flip 1 bit of data -> write
//	FRAM_Read(&Fram, 2, &read_data);
//	read_data ^= 0x08;
//	FRAM_Write(&Fram, 2, &read_data);
//	FRAM_Seq_Read(&Fram, 0, after_flip, 9);
	before_flip[2] ^= 0x08;
	printf("This is the encode data after we flip 1 bit. 0x");
	for (int i = 0; i < 9; i++) {
		printf("%x", before_flip[i]);
	}
	printf("\n");
	//read -> decode
	FRAM_Encode_Read_Block(&Fram, 0, 0, (uint32_t*) &read_first_data);
	FRAM_Encode_Read_Block(&Fram, 0, 1, &read_second_data);
	printf("This is the data after we decode. %f, %u\n", write_first_data,
			(unsigned int) write_second_data);

//	uint8_t base_data[8] = { 1, 2, 3, 4, 5, 6, 7, 8 };
//	uint8_t base_data_plus[9] = { 0 };
//
//	HAL_GPIO_WritePin(SPI6_CS_GPIO_Port, SPI6_CS_Pin, 0);
//	hamming7264_encode(base_data, base_data_plus);
//	HAL_GPIO_WritePin(SPI6_CS_GPIO_Port, SPI6_CS_Pin, 1);
//	HAL_Delay(1);
//	final_ans[1] = (final_ans[1] ^ 0x40);
//	HAL_GPIO_WritePin(SPI6_CS_GPIO_Port, SPI6_CS_Pin, 0);
//	hamming7264_decode(base_data_plus, final_ans);
//	HAL_GPIO_WritePin(SPI6_CS_GPIO_Port, SPI6_CS_Pin, 1);
//	HAL_Delay(1);
//	HAL_GPIO_WritePin(SPI6_CS_GPIO_Port, SPI6_CS_Pin, 0);
//	FRAM_Encode_Write(&Fram, 1, base_data);
//	HAL_GPIO_WritePin(SPI6_CS_GPIO_Port, SPI6_CS_Pin, 1);
//	HAL_Delay(1);
//	uint8_t data_buffff = 0;
//	FRAM_Read(&Fram, 2, &data_buffff);
//	data_buffff = data_buffff ^ 0x80;
//	FRAM_Write(&Fram, 2, &data_buffff);
//	HAL_Delay(1);
//	HAL_GPIO_WritePin(SPI6_CS_GPIO_Port, SPI6_CS_Pin, 0);
//	FRAM_Decode_Read(&Fram, 1, final_ans);
//	HAL_GPIO_WritePin(SPI6_CS_GPIO_Port, SPI6_CS_Pin, 1);
//	printf("test");
//	for (int i = 0; i < 8; i++) {
//		printf("%d", final_ans[i]);
//	}

//	// fame's check method
//	printf("start\n");
//	uint8_t famefame_dataword[8] = {3,2,3,2,4,1,2,3};
//	uint8_t famefame_codeword[9] = {0};
//	uint8_t imposter[9] = {0};
//	hamming7264_encode(famefame_dataword, famefame_codeword);
//	memcpy(imposter, famefame_codeword, 9);
//	famefame_codeword[2] ^= 0x01;
//	for (int i = 0; i < 910; i++){
//		FRAM_Seq_Write(&Fram, (i*9), famefame_codeword, 9);
//	}
//
//	uint8_t fuckfuck[8190] = {0};
//	uint8_t *addres_boy = fuckfuck;
//	uint8_t final_ans[8] = {0};
//	HAL_GPIO_WritePin(LED3_GPIO_Port, LED3_Pin, 1);
//	HAL_GPIO_WritePin(SPI6_CS_GPIO_Port, SPI6_CS_Pin, 0);
////	for (int i = 0; i < 910; i++){
////		FRAM_Decode_Read(&Fram, (i*9), final_ans);
////	}
//	FRAM_Seq_Read(&Fram, 0, fuckfuck, 8190);
//	uint8_t result_fck = 0;
//	for (int i = 0; i < 910; i++){
//		result_fck = hamming7264_decode(addres_boy, final_ans);
//		addres_boy += 9;
//		if (result_fck == 1){
//			hamming7264_encode(final_ans, addres_boy);
//		}
//	}
//	FRAM_Seq_Write(&Fram, 0, fuckfuck, 8190);
//	HAL_GPIO_WritePin(SPI6_CS_GPIO_Port, SPI6_CS_Pin, 1);
//	printf("final ans = ");
//	for(int i = 0; i <8;i++){
//		printf("%d", final_ans[i]);
//	}
//	printf("\n");

//	Check All Memory

//	printf("\n\n\n");
//	#define block_count 20
//	float write_first_data_B = 123.45345;
//	uint32_t write_second_data_B = 64891;
//	HAL_Delay(5);
//	for (uint16_t i = 0; i < block_count; i++) {
//		FRAM_Encode_Write_Block(&Fram, i, (uint32_t*) &write_first_data_B,
//				&write_second_data_B);
//	}
//
//	uint8_t before_flip_20_block[9 * block_count] = { 0 };
//	uint8_t after_flip_20_block[9 * block_count] = { 0 };
//	uint8_t before_Scrubbing_20_block[9 * block_count] = { 0 };
//	uint8_t after_Scrubbing_20_block[9 * block_count] = { 0 };
//
//	HAL_GPIO_WritePin(SPI6_CS_GPIO_Port, SPI6_CS_Pin, 0);
//	FRAM_Seq_Read(&Fram, 0, before_flip_20_block, 9 * block_count);
//	HAL_GPIO_WritePin(SPI6_CS_GPIO_Port, SPI6_CS_Pin, 1);
//	HAL_Delay(1);
//
//	memcpy(after_flip_20_block, before_flip_20_block, 9 * block_count);
//	for (uint16_t i = 0; i < block_count; i++) {
//		after_flip_20_block[(i * 9) + (TIM7->CNT % 8)] ^= (TIM7->CNT % 255);
//		HAL_Delay(2);
//	}
//
//	HAL_GPIO_WritePin(SPI6_CS_GPIO_Port, SPI6_CS_Pin, 0);
//	FRAM_Seq_Write(&Fram, 0, after_flip_20_block, 9 * block_count);
//	HAL_GPIO_WritePin(SPI6_CS_GPIO_Port, SPI6_CS_Pin, 1);
//	HAL_Delay(1);
//
//	FRAM_Seq_Read(&Fram, 0, before_Scrubbing_20_block, 9 * block_count);
//
//	HAL_GPIO_WritePin(SPI6_CS_GPIO_Port, SPI6_CS_Pin, 0);
//	FRAM_Scrubbing(&Fram, block_count);
//	HAL_GPIO_WritePin(SPI6_CS_GPIO_Port, SPI6_CS_Pin, 1);
//	HAL_Delay(1);
//
//	FRAM_Seq_Read(&Fram, 0, after_Scrubbing_20_block, 9 * block_count);
//
//	for (uint16_t i = 0; i < (9 * block_count); i++) {
//		if (before_flip_20_block[i] == after_Scrubbing_20_block[i]) {
//			if (before_flip_20_block[i] != after_flip_20_block[i]) {
//				printf("0x%x\t0x%x\t0x%x\t0x%x  <--- Flip \n",
//						before_flip_20_block[i], after_Scrubbing_20_block[i],
//						before_Scrubbing_20_block[i], after_flip_20_block[i]);
//			} else {
//				printf("0x%x\t0x%x\t0x%x\t0x%x \n", before_flip_20_block[i],
//						after_Scrubbing_20_block[i],
//						before_Scrubbing_20_block[i], after_flip_20_block[i]);
//
//			}
//		} else {
//			printf("0x%x\t0x%x\t0x%x\t0x%x ---->Fail!!<---- \n",
//					before_flip_20_block[i], after_Scrubbing_20_block[i],
//					before_Scrubbing_20_block[i], after_flip_20_block[i]);
//		}
//		if (i % 9 == 8) {
//			printf("%d ----------------------------------\n", i);
//		}
//	}
}

PUTCHAR_PROTOTYPE {
	/* Place your implementation of fputc here */
	/* e.g. write a character to the EVAL_COM1 and Loop until the end of transmission */
	HAL_UART_Transmit(&huart3, (uint8_t*) &ch, 1, 1);

	return ch;
}

void HAL_TIM_PeriodElapsedCallback(TIM_HandleTypeDef *htim) {
	if (htim == &htim7) {
		_micro += 65535;
	}
}

uint64_t micro(){
	return _micro + TIM7->CNT;
}
/* USER CODE END 4 */
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


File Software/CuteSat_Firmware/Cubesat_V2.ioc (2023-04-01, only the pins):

Mcu.UserName=STM32H743ZITx
PA11.Signal=USB_OTG_FS_DM
PA12.Signal=USB_OTG_FS_DP
PA2.Signal=USART2_TX
PA3.Signal=USART2_RX
PA4.GPIO_Label=SPI1_CS
PA4.Signal=GPIO_Output
PA5.Signal=SPI1_SCK
PA6.Signal=SPI1_MISO
PA7.Signal=SPI1_MOSI
PB10.Signal=USART3_TX
PB11.Signal=USART3_RX
PB12.GPIO_Label=FRAM_CS
PB12.Signal=GPIO_Output
PB13.Signal=SPI2_SCK
PB14.Signal=SPI2_MISO
PB15.Signal=SPI2_MOSI
PB5.Signal=S_TIM3_CH2
PB6.Signal=I2C1_SCL
PB7.Signal=I2C1_SDA
PB8.Signal=I2C4_SCL
PB9.Signal=I2C4_SDA
PC0.Signal=ADCx_INP10
PC1.Signal=ADCx_INP11
PC10.Signal=SDMMC1_D2
PC11.Signal=SDMMC1_D3
PC12.Signal=SDMMC1_CK
PC2_C.GPIO_Label=ALERT_INA238_1
PC2_C.Signal=GPIO_Input
PC3_C.GPIO_Label=ALERT_INA238_2
PC3_C.Signal=GPIO_Input
PC8.Signal=SDMMC1_D0
PC9.Signal=SDMMC1_D1
PD0.GPIO_Label=SDMMC_DETECT
PD0.Signal=GPIO_Input
PD2.Signal=SDMMC1_CMD
PD8.GPIO_Label=FRAM_HOLD
PD8.Signal=GPIO_Output
PD9.GPIO_Label=FRAM_WP
PD9.Signal=GPIO_Output
PE0.GPIO_Label=WDI2
PE0.Signal=GPIO_Output
PE1.GPIO_Label=WDI1
PE1.Signal=GPIO_Output
PE11.Signal=S_TIM1_CH2
PE4.GPIO_Label=D1_DIR
PE4.Signal=GPIO_Output
PE5.GPIO_Label=D1_SPEED
PE5.Signal=GPIO_Output
PE9.Signal=S_TIM1_CH1
PF0.Signal=I2C2_SDA
PF1.Signal=I2C2_SCL
PF14.GPIO_Label=LED4
PF14.Signal=GPIO_Output
PF15.GPIO_Label=LED3
PF15.Signal=GPIO_Output
PF2.GPIO_Label=TEMP_ALERT
PF2.Signal=GPIO_Input
PF7.GPIO_Label=D2_SPEED
PF7.Signal=GPIO_Output
PF8.GPIO_Label=D2_DIR
PF8.Signal=GPIO_Output
PG0.GPIO_Label=LED2
PG0.Signal=GPIO_Output
PG1.GPIO_Label=LED1
PG1.Signal=GPIO_Output
PG11.GPIO_Label=SPI6_CS
PG11.Signal=GPIO_Output
PG12.Signal=SPI6_MISO
PG13.Signal=SPI6_SCK
PG14.Signal=SPI6_MOSI

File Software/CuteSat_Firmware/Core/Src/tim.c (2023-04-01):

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
/* Includes ------------------------------------------------------------------*/
#include "tim.h"

TIM_HandleTypeDef htim1;
TIM_HandleTypeDef htim2;
TIM_HandleTypeDef htim3;
TIM_HandleTypeDef htim4;
TIM_HandleTypeDef htim6;
TIM_HandleTypeDef htim7;
TIM_HandleTypeDef htim15;
TIM_HandleTypeDef htim17;
DMA_HandleTypeDef hdma_tim2_ch1;

/* TIM1 init function */
void MX_TIM1_Init(void)
{

  TIM_Encoder_InitTypeDef sConfig = {0};
  TIM_MasterConfigTypeDef sMasterConfig = {0};

  htim1.Instance = TIM1;
  htim1.Init.Prescaler = 0;
  htim1.Init.CounterMode = TIM_COUNTERMODE_UP;
  htim1.Init.Period = 65535;
  htim1.Init.ClockDivision = TIM_CLOCKDIVISION_DIV1;
  htim1.Init.RepetitionCounter = 0;
  htim1.Init.AutoReloadPreload = TIM_AUTORELOAD_PRELOAD_ENABLE;
  sConfig.EncoderMode = TIM_ENCODERMODE_TI12;
  sConfig.IC1Polarity = TIM_ICPOLARITY_RISING;
  sConfig.IC1Selection = TIM_ICSELECTION_DIRECTTI;
  sConfig.IC1Prescaler = TIM_ICPSC_DIV1;
  sConfig.IC1Filter = 10;
  sConfig.IC2Polarity = TIM_ICPOLARITY_RISING;
  sConfig.IC2Selection = TIM_ICSELECTION_DIRECTTI;
  sConfig.IC2Prescaler = TIM_ICPSC_DIV1;
  sConfig.IC2Filter = 0;
  if (HAL_TIM_Encoder_Init(&htim1, &sConfig) != HAL_OK)
  {
    Error_Handler();
  }
  sMasterConfig.MasterOutputTrigger = TIM_TRGO_RESET;
  sMasterConfig.MasterOutputTrigger2 = TIM_TRGO2_RESET;
  sMasterConfig.MasterSlaveMode = TIM_MASTERSLAVEMODE_DISABLE;
  if (HAL_TIMEx_MasterConfigSynchronization(&htim1, &sMasterConfig) != HAL_OK)
  {
    Error_Handler();
  }
}
/* TIM2 init function */
void MX_TIM2_Init(void)
{

  TIM_ClockConfigTypeDef sClockSourceConfig = {0};
  TIM_MasterConfigTypeDef sMasterConfig = {0};
  TIM_OC_InitTypeDef sConfigOC = {0};

  htim2.Instance = TIM2;
  htim2.Init.Prescaler = 0;
  htim2.Init.CounterMode = TIM_COUNTERMODE_UP;
  htim2.Init.Period = 300 - 1;
  htim2.Init.ClockDivision = TIM_CLOCKDIVISION_DIV1;
  htim2.Init.AutoReloadPreload = TIM_AUTORELOAD_PRELOAD_DISABLE;
  if (HAL_TIM_Base_Init(&htim2) != HAL_OK)
  {
    Error_Handler();
  }
  sClockSourceConfig.ClockSource = TIM_CLOCKSOURCE_INTERNAL;
  if (HAL_TIM_ConfigClockSource(&htim2, &sClockSourceConfig) != HAL_OK)
  {
    Error_Handler();
  }
  if (HAL_TIM_PWM_Init(&htim2) != HAL_OK)
  {
    Error_Handler();
  }
  sMasterConfig.MasterOutputTrigger = TIM_TRGO_RESET;
  sMasterConfig.MasterSlaveMode = TIM_MASTERSLAVEMODE_DISABLE;
  if (HAL_TIMEx_MasterConfigSynchronization(&htim2, &sMasterConfig) != HAL_OK)
  {
    Error_Handler();
  }
  sConfigOC.OCMode = TIM_OCMODE_PWM1;
  sConfigOC.Pulse = 0;
  sConfigOC.OCPolarity = TIM_OCPOLARITY_HIGH;
  sConfigOC.OCFastMode = TIM_OCFAST_DISABLE;
  if (HAL_TIM_PWM_ConfigChannel(&htim2, &sConfigOC, TIM_CHANNEL_1) != HAL_OK)
  {
    Error_Handler();
  }
  HAL_TIM_MspPostInit(&htim2);

}
/* TIM3 init function */
void MX_TIM3_Init(void)
{

  TIM_Encoder_InitTypeDef sConfig = {0};
  TIM_MasterConfigTypeDef sMasterConfig = {0};

  htim3.Instance = TIM3;
  htim3.Init.Prescaler = 0;
  htim3.Init.CounterMode = TIM_COUNTERMODE_UP;
  htim3.Init.Period = 65535;
  htim3.Init.ClockDivision = TIM_CLOCKDIVISION_DIV1;
  htim3.Init.AutoReloadPreload = TIM_AUTORELOAD_PRELOAD_ENABLE;
  sConfig.EncoderMode = TIM_ENCODERMODE_TI12;
  sConfig.IC1Polarity = TIM_ICPOLARITY_RISING;
  sConfig.IC1Selection = TIM_ICSELECTION_DIRECTTI;
  sConfig.IC1Prescaler = TIM_ICPSC_DIV1;
  sConfig.IC1Filter = 10;
  sConfig.IC2Polarity = TIM_ICPOLARITY_RISING;
  sConfig.IC2Selection = TIM_ICSELECTION_DIRECTTI;
  sConfig.IC2Prescaler = TIM_ICPSC_DIV1;
  sConfig.IC2Filter = 0;
  if (HAL_TIM_Encoder_Init(&htim3, &sConfig) != HAL_OK)
  {
    Error_Handler();
  }
  sMasterConfig.MasterOutputTrigger = TIM_TRGO_RESET;
  sMasterConfig.MasterSlaveMode = TIM_MASTERSLAVEMODE_DISABLE;
  if (HAL_TIMEx_MasterConfigSynchronization(&htim3, &sMasterConfig) != HAL_OK)
  {
    Error_Handler();
  }
}
/* TIM4 init function */
void MX_TIM4_Init(void)
{

  TIM_ClockConfigTypeDef sClockSourceConfig = {0};
  TIM_MasterConfigTypeDef sMasterConfig = {0};
  TIM_OC_InitTypeDef sConfigOC = {0};

  htim4.Instance = TIM4;
  htim4.Init.Prescaler = 240 - 1;
  htim4.Init.CounterMode = TIM_COUNTERMODE_UP;
  htim4.Init.Period = 1000;
  htim4.Init.ClockDivision = TIM_CLOCKDIVISION_DIV1;
  htim4.Init.AutoReloadPreload = TIM_AUTORELOAD_PRELOAD_ENABLE;
  if (HAL_TIM_Base_Init(&htim4) != HAL_OK)
  {
    Error_Handler();
  }
  sClockSourceConfig.ClockSource = TIM_CLOCKSOURCE_INTERNAL;
  if (HAL_TIM_ConfigClockSource(&htim4, &sClockSourceConfig) != HAL_OK)
  {
    Error_Handler();
  }
  if (HAL_TIM_PWM_Init(&htim4) != HAL_OK)
  {
    Error_Handler();
  }
  sMasterConfig.MasterOutputTrigger = TIM_TRGO_UPDATE;
  sMasterConfig.MasterSlaveMode = TIM_MASTERSLAVEMODE_DISABLE;
  if (HAL_TIMEx_MasterConfigSynchronization(&htim4, &sMasterConfig) != HAL_OK)
  {
    Error_Handler();
  }
  sConfigOC.OCMode = TIM_OCMODE_PWM1;
  sConfigOC.Pulse = 500;
  sConfigOC.OCPolarity = TIM_OCPOLARITY_HIGH;
  sConfigOC.OCFastMode = TIM_OCFAST_DISABLE;
  if (HAL_TIM_PWM_ConfigChannel(&htim4, &sConfigOC, TIM_CHANNEL_1) != HAL_OK)
  {
    Error_Handler();
  }
}
/* TIM6 init function */
void MX_TIM6_Init(void)
{

  TIM_MasterConfigTypeDef sMasterConfig = {0};

  htim6.Instance = TIM6;
  htim6.Init.Prescaler = 240-1;
  htim6.Init.CounterMode = TIM_COUNTERMODE_UP;
  htim6.Init.Period = 65535;
  htim6.Init.AutoReloadPreload = TIM_AUTORELOAD_PRELOAD_DISABLE;
  if (HAL_TIM_Base_Init(&htim6) != HAL_OK)
  {
    Error_Handler();
  }
  sMasterConfig.MasterOutputTrigger = TIM_TRGO_RESET;
  sMasterConfig.MasterSlaveMode = TIM_MASTERSLAVEMODE_DISABLE;
  if (HAL_TIMEx_MasterConfigSynchronization(&htim6, &sMasterConfig) != HAL_OK)
  {
    Error_Handler();
  }
}
/* TIM7 init function */
void MX_TIM7_Init(void)
{

  TIM_MasterConfigTypeDef sMasterConfig = {0};

  htim7.Instance = TIM7;
  htim7.Init.Prescaler = 240 - 1;
  htim7.Init.CounterMode = TIM_COUNTERMODE_UP;
  htim7.Init.Period = 65535;
  htim7.Init.AutoReloadPreload = TIM_AUTORELOAD_PRELOAD_ENABLE;
  if (HAL_TIM_Base_Init(&htim7) != HAL_OK)
  {
    Error_Handler();
  }
  sMasterConfig.MasterOutputTrigger = TIM_TRGO_RESET;
  sMasterConfig.MasterSlaveMode = TIM_MASTERSLAVEMODE_DISABLE;
  if (HAL_TIMEx_MasterConfigSynchronization(&htim7, &sMasterConfig) != HAL_OK)
  {
    Error_Handler();
  }
}
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

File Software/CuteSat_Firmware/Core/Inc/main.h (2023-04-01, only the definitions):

#define D1_DIR_Pin GPIO_PIN_4
#define D1_DIR_GPIO_Port GPIOE
#define D1_SPEED_Pin GPIO_PIN_5
#define D1_SPEED_GPIO_Port GPIOE
#define TEMP_ALERT_Pin GPIO_PIN_2
#define TEMP_ALERT_GPIO_Port GPIOF
#define D2_SPEED_Pin GPIO_PIN_7
#define D2_SPEED_GPIO_Port GPIOF
#define D2_DIR_Pin GPIO_PIN_8
#define D2_DIR_GPIO_Port GPIOF
#define ALERT_INA238_1_Pin GPIO_PIN_2
#define ALERT_INA238_1_GPIO_Port GPIOC
#define ALERT_INA238_2_Pin GPIO_PIN_3
#define ALERT_INA238_2_GPIO_Port GPIOC
#define SPI1_CS_Pin GPIO_PIN_4
#define SPI1_CS_GPIO_Port GPIOA
#define LED4_Pin GPIO_PIN_14
#define LED4_GPIO_Port GPIOF
#define LED3_Pin GPIO_PIN_15
#define LED3_GPIO_Port GPIOF
#define LED2_Pin GPIO_PIN_0
#define LED2_GPIO_Port GPIOG
#define LED1_Pin GPIO_PIN_1
#define LED1_GPIO_Port GPIOG
#define FRAM_CS_Pin GPIO_PIN_12
#define FRAM_CS_GPIO_Port GPIOB
#define FRAM_HOLD_Pin GPIO_PIN_8
#define FRAM_HOLD_GPIO_Port GPIOD
#define FRAM_WP_Pin GPIO_PIN_9
#define FRAM_WP_GPIO_Port GPIOD
#define SDMMC_DETECT_Pin GPIO_PIN_0
#define SDMMC_DETECT_GPIO_Port GPIOD
#define SPI6_CS_Pin GPIO_PIN_11
#define SPI6_CS_GPIO_Port GPIOG
#define WDI2_Pin GPIO_PIN_0
#define WDI2_GPIO_Port GPIOE
#define WDI1_Pin GPIO_PIN_1
#define WDI1_GPIO_Port GPIOE

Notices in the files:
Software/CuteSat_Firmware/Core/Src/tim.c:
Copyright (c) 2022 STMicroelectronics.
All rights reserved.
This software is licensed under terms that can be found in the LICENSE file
